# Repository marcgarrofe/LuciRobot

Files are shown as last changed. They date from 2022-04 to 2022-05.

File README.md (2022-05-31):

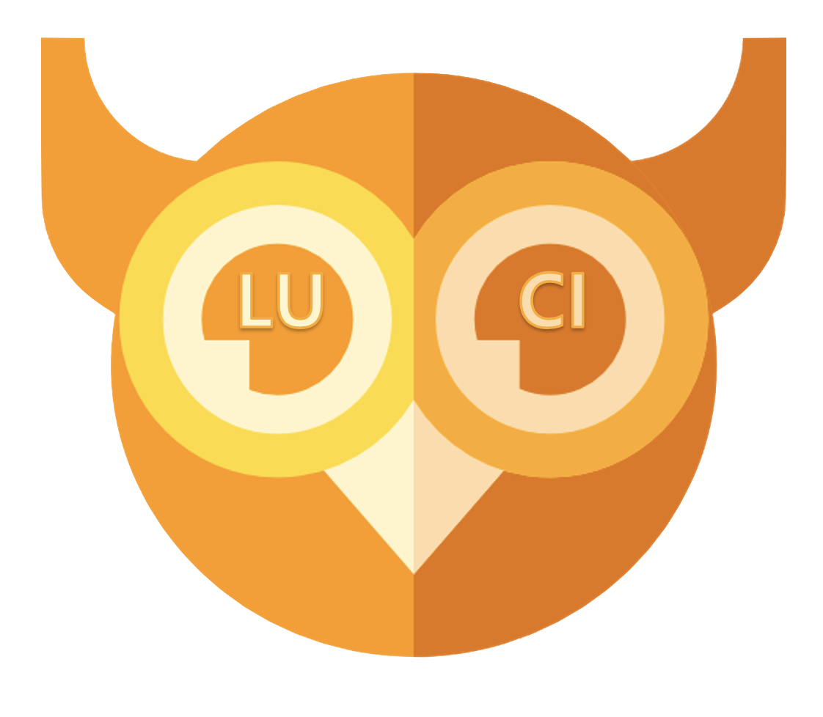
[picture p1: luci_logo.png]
header pic


# Luci
Human seeker robot in hostile environments.

# Table of Contents
   * [What is this?](#what-is-this)
   * [Requirements](#requirements)
   * [How to use](#how-to-use)
   * [Controller panel](#controller-panel)
   * [Driving](#driving-modes)
   * [Speech to text](#speech-to-text)
   * [Image processing](#image-processing)
   * [Person detector](#person-detector)
   * [License](#license)
   * [Contribution](#contribution)
   * [Authors](#authors)

# What is this?

Luci is a human detector robot designed to locate people inside hostile enviroments such as gas, smoke or fire. 

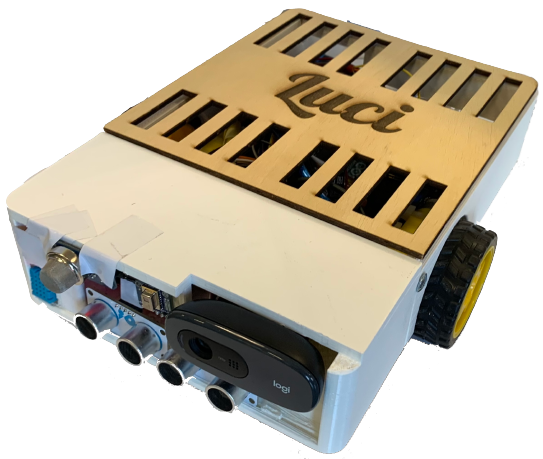
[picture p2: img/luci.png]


Features:

1. Easy to controll and operate.

2. Widely range of sensor and cameras.

3. Small and fast.

# Requirements

For running each sample code:

- [Python 3.10.x](https://www.python.org/)

- [C++]

- [Flask/socket.io](https://socket.io/)

- [PySerial](https://pypi.org/project/pyserial/)

- [OpenCV](https://opencv.org/)

- [VidGear](https://abhitronix.github.io/vidgear/v0.2.5-stable/)

- [Google Cloud Speech](https://cloud.google.com/speech-to-text)

- [PyAudio](https://pypi.org/project/PyAudio/)

- [Adafruit](https://www.adafruit.com/)

- [NumPy](https://numpy.org/)

# How to use

- Step 1:
`cd code`

- Step 2:
`pip install -r requirements.txt` 

- Step 3:
`python main.py`

- Step 4:
Isn't it beautiful?

# Controller panel

Luci has a build-in controller panel web server. Her user-friendly interface allows the operator to see through Luci's eyes and sensors can drive where none can arrive.

Luci's has a wide range of sensors such as: gas sensor, distance, temperature, humidity, microphone and two cameras. You can see all the sensors displaying below:

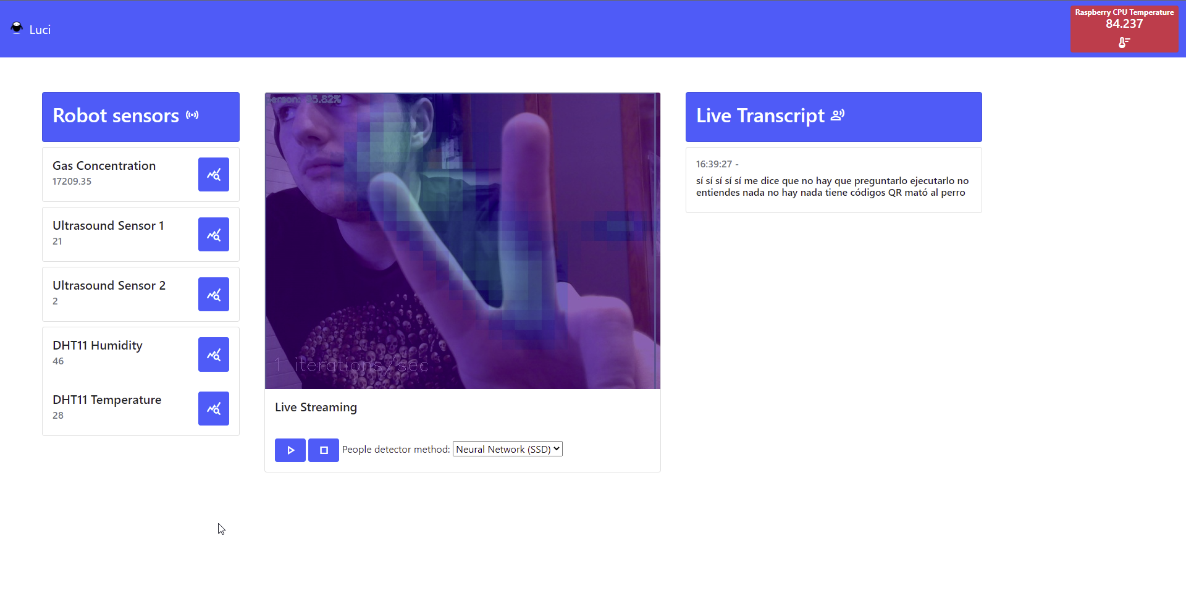
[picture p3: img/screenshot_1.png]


# Driving modes

In order to perform more accurate driving experience, Luci is controlled with a gamepad. This cool feature allows the operator to control each wheal movement and speed separately in order to get a better accuracy movement.

# Speech to text

Luci's microphone can recognize voice and convert it to text. This feature is founded on the controller panel and allows the operator to read the live transcription of the room's voice.

# Image processing

The robot's eyes are formed of a wide-range camera and a thermal camera that combined using image processing provides an RGB realtime image with temperature coloring.

Finally, in order to drive and have a real time image from Luci, she has a build in video stabilization developed with software that uses a wide range of image stabilization such as: KeyPoint matching, Fourier image superposition and Optical Flow. Each age can be called by the operator in order to find the implementation that works best for each situation.

# Person detector

Luci's computer runs a Neuronal Network that detects people and animals in the room. This tool helps the firefighters to identify the number of people inside a building and combined with the thermal camera we can determinate the state of the subject.

# License 

MIT

# Contribution

Any contribution is welcome!! 

# Authors
 * [Marti Caixal](https://github.com/marti1999)
 * [Hernan Capilla](https://github.com/hcapilla)
 * [Marc Garrofe](https://github.com/marcgarrofe)
 * [Ricard Lopez](https://github.com/Ricardlol)
 * [Bruno Moya](https://github.com/elblogbruno)

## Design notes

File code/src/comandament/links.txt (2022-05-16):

https://create.arduino.cc/projecthub/72359/controlling-a-robot-with-a-playstation-controller-15741e
https://pimylifeup.com/raspberry-pi-playstation-controllers/
https://wouterdeschuyter.be/blog/configure-a-ps3-controller-to-automatically-connect-to-a-raspberry-pi

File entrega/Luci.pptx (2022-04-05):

## LUCi

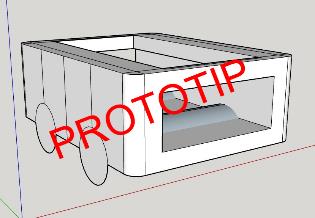
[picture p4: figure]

GROUP_16
Martí Caixal Joaquinet
Hernán Capilla Urbano
Marc Garrofé Urrutia
Ricard Lopez Olivares
Bruno Moya Ruíz

Robot amb l’objectiu de localitzar persones en risc a terrenys hostils per humans

Robòtica, llenguatge I planificació – Enginyeria informàtica - uab

## LUCI

Component | Units | Price/unit | Budget
Raspberry Pi 3 B+ | 1 | 35 | 35
Gravity: Sensor de gases | 1 | 6,5 | 41,5
Sensor de distancia por ultrasondos HC-SR04 | 2 | 1,8 | 45,1
Arduin UNO REV.3, | 1 | 15 | 60,1
Kit motores: DAGU 140RPM | 1 | 5,59 | 65,69
Cable de pila 9V | 1 | 0,79 | 66,48
MLX90640 Thermal Camera Breakout | 1 | 53,55 | 119,55
WEBCAM C160 | 1 | 12,8 | 132,35
Sensor TEMP./HUMEDAD | 1 | 4,02 | 136,37
POWER BANK 5000 | 1 | 7,91 | 144,28
L93B QUAD PUSH | 1 | 2,15 | 146,91
TOTAL: | | | 146,91

## Altres enllaços

Projecte en el qual està inspirat

https://www.eltiempo.com/tecnosfera/novedades-tecnologia/firebot-el-robot-que-ayuda-a-prevenir-incendios-forestales-103122

- https://github.com/gritmind/image-processing-for-fire-detection
- https://makersportal.com/blog/2020/6/8/high-resolution-thermal-camera-with-raspberry-pi-and-mlx90640

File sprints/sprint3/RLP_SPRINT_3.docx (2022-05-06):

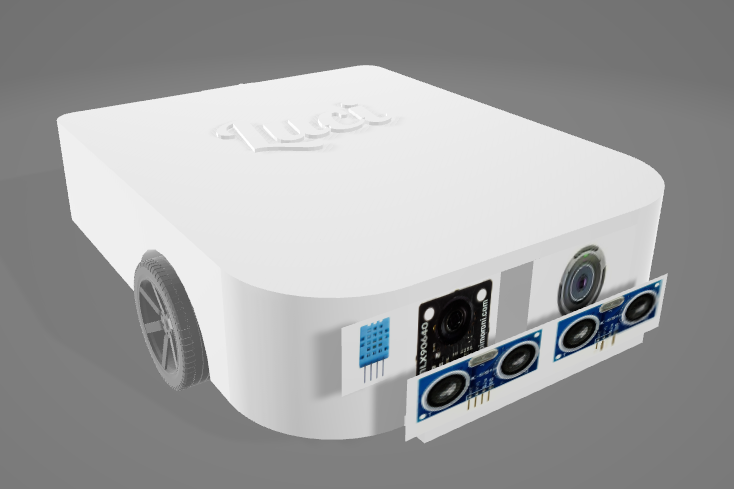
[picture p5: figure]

# Luci

Human seeker robot in hostile environments

PROJECT SPRINT #3.
DATE: 4th May 2022

Martí Caixal i Joniquet
Ricard Lopez Olivares
Hernán Capilla Urbano
Bruno Moya Ruiz
Marc Garrofé Urrutia

Luci

Human seeker robot in hostile environments

# Project description

This robot’s aim is to seek people whose situation is not favorable in hostile environments. It searchs, avoids obstacles, detects humans in environments where people can’t afford to get in (such as gas, smoke, or buildings on fire) and notifies the emergency units.

“Luci keeps you safe, from environments where you won’t be safe.”

# Electronic components

This is the list of the used components:

- Raspberry Pi 3 B+
- Gravity: Gas sensor
- Ultrasound HC-SR04 distance sensor
- Arduino UNO Rev.3
- Motor Kit: DAGU 140rpm
- 9V battery cable
- MLX90640 Thermal Camera Breakout
- Webcam C160
- Temperature/Humidity sensor
- Power Bank 5000
- L93B Quad Push

# Hardware Scheme

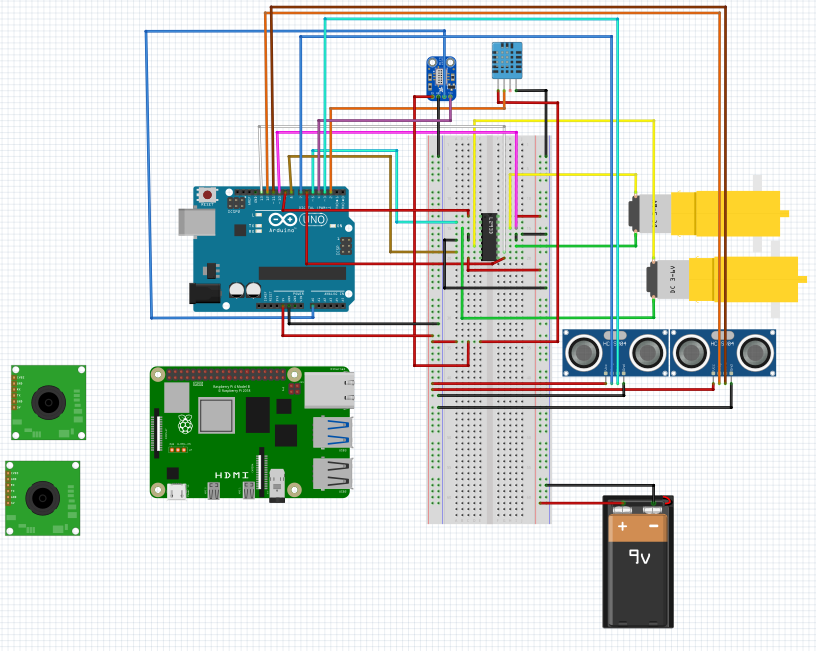
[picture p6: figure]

# Software Architecture

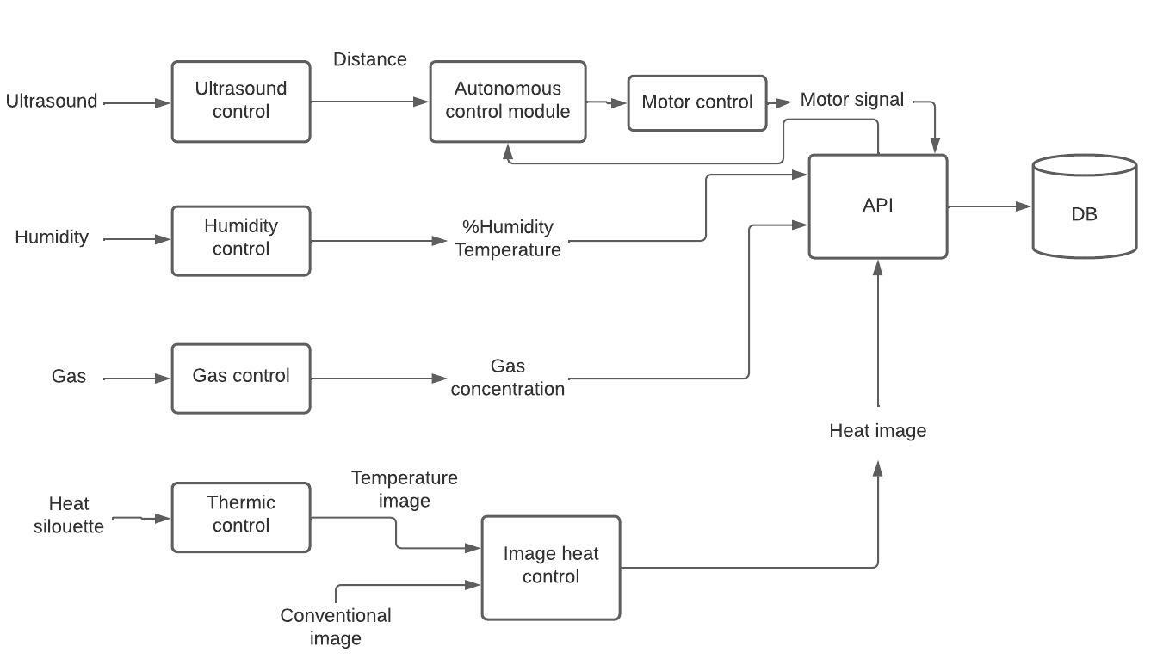
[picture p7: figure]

# Amazing contributions

Mixing Compting Vision + Robotics with the purpose of analyzing normal images and thermic images to get the results.

Adaptive robot to different environments such as gas, fire, smoke, etc.

Not only detects but notifies.

Not only notifies but it also indicates the path that has followed the robot plus the obstacles that have found on its way.

# Extra components and 3D pieces

- Design 3 pieces First we have the base of the robot. This one presents the part for puting the motors and wheels, also with all the essential elements like Arduino or Raspberry.
- Here we can see it empty:

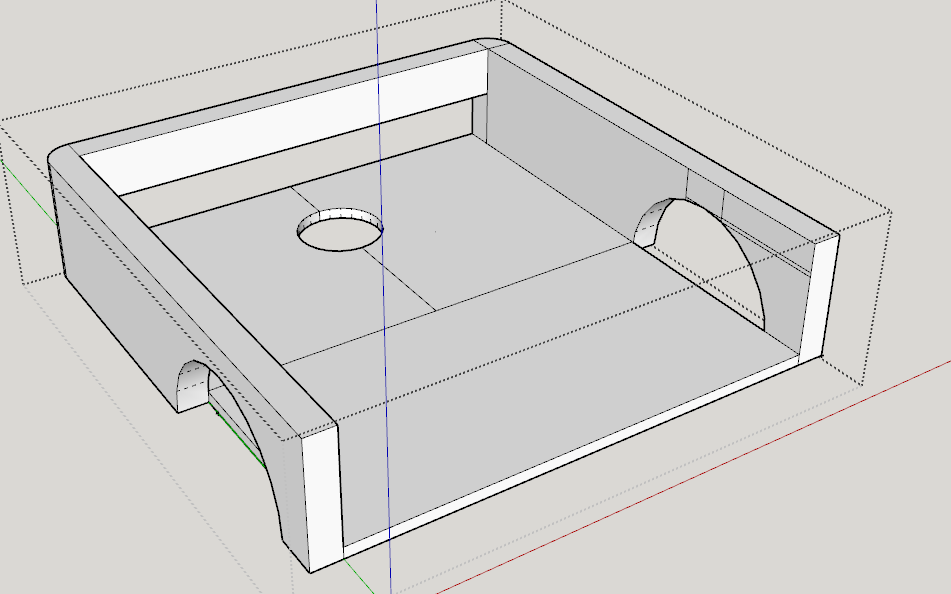
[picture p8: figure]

- The idea of this rectangular format at the end (which is not definitive) is to install all the electronics and in this way to be able to connect the arduino to the computer with the cable, so with the batteries witouth having to take them off. The hole is currently very Big, once we have all the electronics we will try to 'measure' and so the cables do fit in perfectly without having a hole on the back.

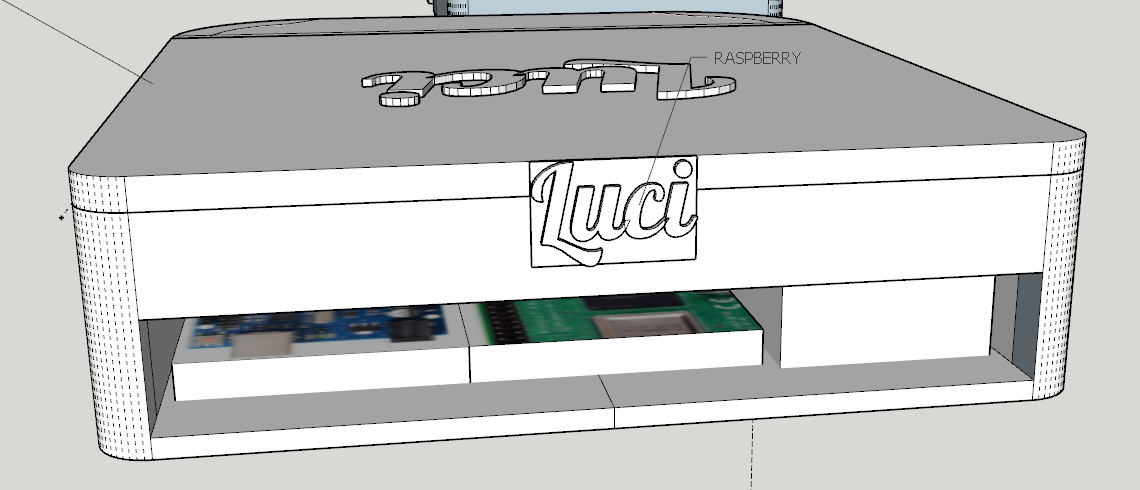
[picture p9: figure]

Next, we have the front part. Here it was necessary to chop the robot in parts due to the the fact that the idea is that everything can be printed on the 3D printer, but apart from that, it presents its benefits.

First of all, it is on where all the sensors and the cameras of the robot will be. Having it separately in a module allows the installation or customization of the module to remain effective without having to modify all the robot chassis. Once all the sensors are plugged in, their cables will go back to where the Arduino and raspberry are.

Attempts have been made to distribute all things so that the robot has a uniform weight around the entire structure, and that it is as small in height as possible so that it can enter more hostile places.

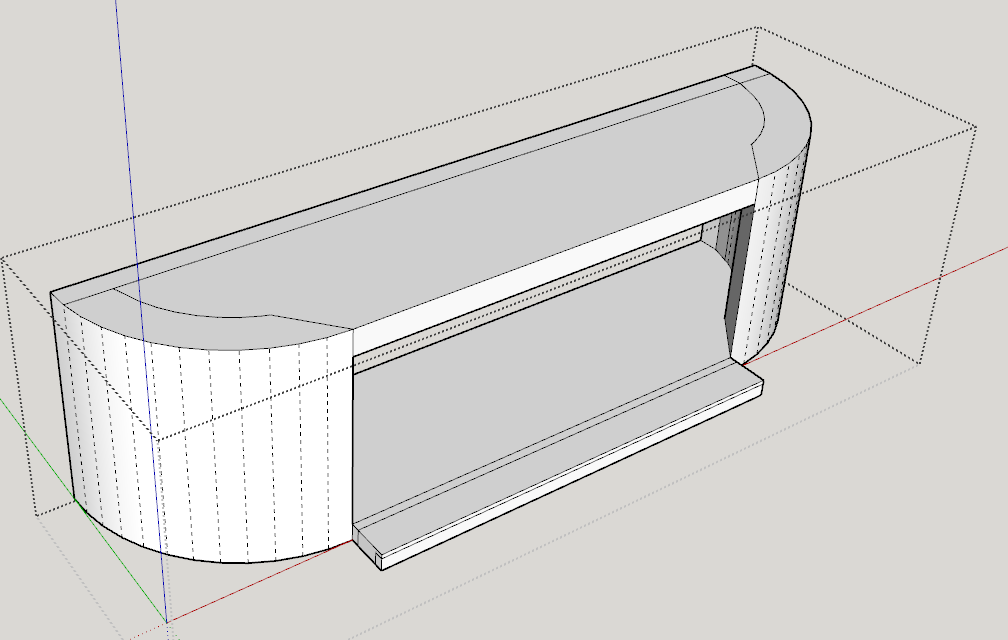
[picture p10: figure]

Finally, we have the cover, which allows us to close the whole system in a homogeneous structure and why not, beautiful, without all the electronics visible and protected at the same time.

The general idea of everything was to make it a versatile and modular robot, to be able to tractor problems individually and also to fit everything in the printing base of a 3D printer.

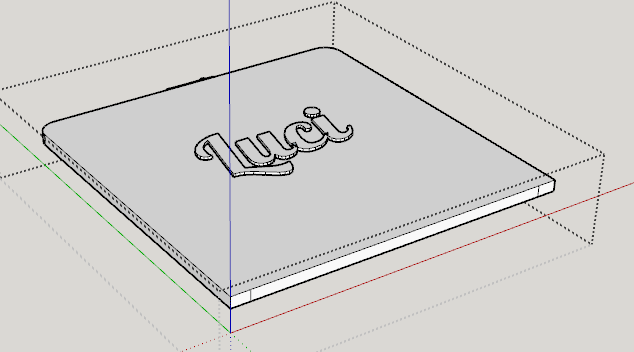
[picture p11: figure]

# Foreseen risks and contingency plan

Risk # | Description | Probability (High/Medium/Low) | Impact (High/Medium/Low) | Contingency plan
1 | Camera not stable | Médium | Low | Stabilize the image sequence although the the FOV would be reduced
2 | Faulty thermal camera | Low | Medium | Refund it and ask for a new camera if possible. Otherwise we would just use the default pi camera for computer vision
3 | Cannot merge both images (normal and thermal camera) | Medium | Medium | Images would be needed to be treated separately. The predictions would likely be worse.
4 | Wheels don’t move smoothly | Medium | Low | The robots would just not move smoothly. If it too much, some smoothing could be created by adding a chicken rubber around the wheels.
5 | Not enough CPU/GPU power | Medium | Medium | Instead of getting the desired 20fps, we would have a lower fps and probably would not be able to use it in real time.
6 | Not enough torque from the motors to move the robot | Low | High | More powerful motors would be required. Another option could be using extra gears to increase torque, but the speed would be decreased.
7 | Don’t know how to connect Arduino and Raspbery pi together | High | Low | We would first try to do it on a PC with a simulator following some tutorials. Once we get to understand it, we would try to do it again now with the physical components.
8 | 3D printed parts are not good or do not fit together with one another or the other electrical components | High | low | If the error is low, we could just file down the edges. Otherwise, some new parts would be to be printed.

# Algo

- OpenCV Optical flow and key points detection in order to stabilizate the camera
- TensorFlow YOLO and SSD neuronal networks for person detection
- MPEG encoding for vídeo streaming

# Updates Sprint 2

- Motors now move in different directions. They go forward, backward, left, right (with the desired speed)
- All sensors working and getting correct input values
- We have python code that reads the sensors values from serial USB and then them them using websockets in real-time to the work in progress javascript-html frontend.
- This allows a communication between Arduino and python in real time, for example for controlling the robot motors from the frontend and whatever idea we want to implement. We can do it either in local or the internet with a free hosting.
- Along with this document, there is a video attached showing the motors move.

# Updates Sprint 3

- On the computer vision field, we are able to identify more than 40 objects using a SSD Deep Learning Net. Also, as a back-up System, we have a Histogram of Gradient Person detector.
- Also, we have developed an image stabilizer using our own module using point feature and homographs translations. As a back-up we have an open-source stabilizer that works better, but it has high latency (about 3 seconds).

As an example, here you can see a testing video (downloaded from Youtube) that we use to see how the stabilizer and the object detector works:

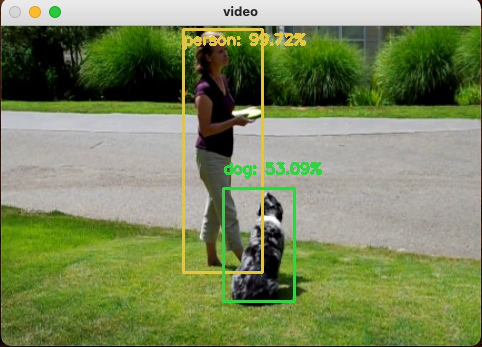
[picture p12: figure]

- Next, we have introduced the communication module between Luci's brain and the operator connected using a web browser. As shown, you can see a basic demonstration of the data coming from the robot's sensors. Thanks to the use of WebSockets (https://socket.io/) we can have this information in real time. This means we can also interact in real time from the dashboard with the raspberry, for example, for sending commands to the raspberry that consequently sends them to the Arduino. This will enable in future updates a control of the robot movement from the website UI.
- We have also added a redesign for it using Bootstrap framework, so it is a nice dashboard to look at, and data is easily available and readable from a human worker perspective:

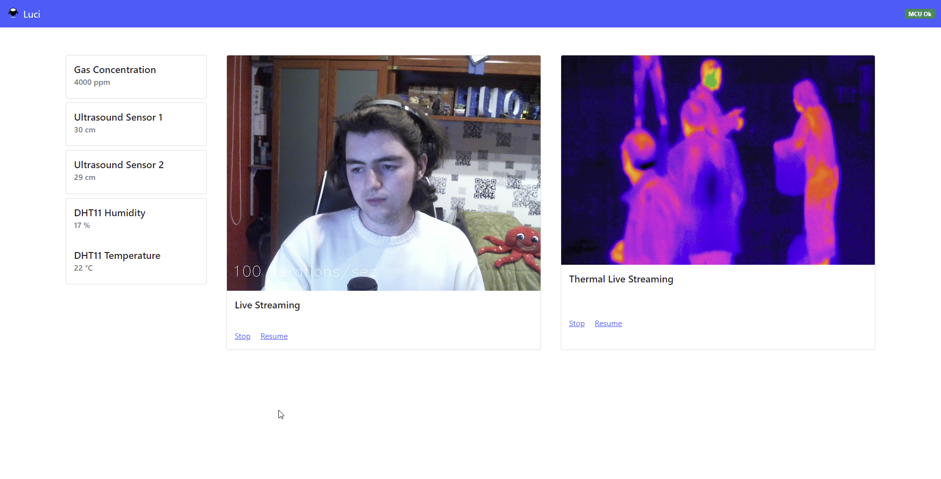
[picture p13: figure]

- Finally, you can see as well that now we also have a live streaming of the RGB Camera (Webcam). The live streaming of the thermal camera by the moment is a placeholder image, as of the time writing this sprint update, has not been given to us or either available on stock (: The catch here it uses threads, that allows us, without any processing of the image yet arrive to greater frames per second. Not only that, but once we connect the computer algorithms seen some lines ago with threads, will allow the raspberry cpu to separate each task on different cpu cores, and do some ‘balancing’
- 3D Wise, we have added some hinge on the cover so we can close and open, but if it adds much unnecessary difficulty to the print, we may remove it and attach the cover with some glue or whatever:

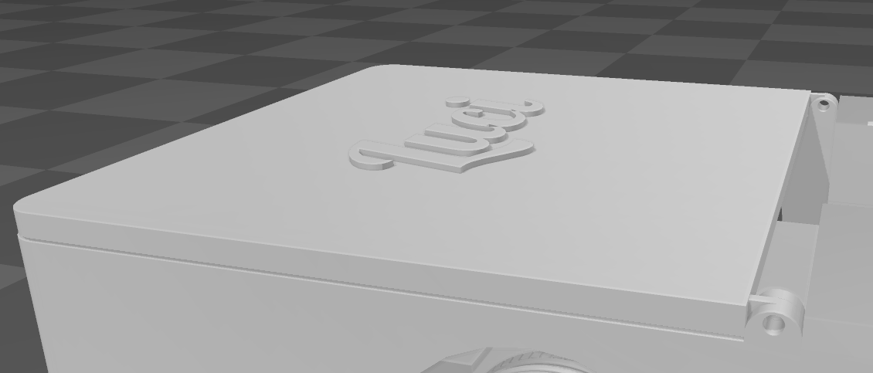
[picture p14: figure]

The sensors part has been redesign for a nicer design but we still are not 100% of it as some sensors may need to be attach with screws, and we prefer something that is easier to print and the sensors to attach:

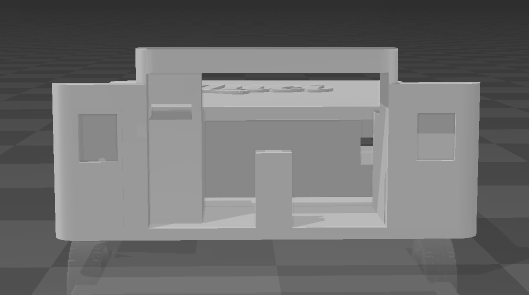
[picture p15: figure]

References

This project has been inspired by the following Internet projects:

URL Link 1: https://www.eltiempo.com/tecnosfera/novedades-tecnologia/firebot-el-robot-que-ayuda-a-prevenir-incendios-forestales-103122

URL Link 2: https://github.com/gritmind/image-processing-for-fire-detection

URL Link 3: https://makersportal.com/blog/2020/6/8/high-resolution-thermal-camera-with-raspberry-pi-and-mlx90640

RLP - Computer Engineering. UAB (Barcelona) 2021-2022

Sprint #1 Date: 14 April 2021

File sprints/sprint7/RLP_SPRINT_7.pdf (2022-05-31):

RLP - Computer Engineering. UAB (Barcelona) 2021-2022

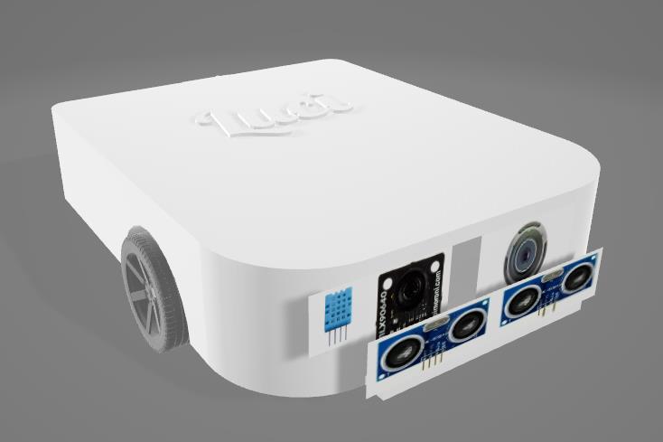
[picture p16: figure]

# Luci

### Human seeker robot in hostile environments

PROJECT SPRINT #7.
DATE: 31th May 2022

Martí Caixal i Joniquet
Ricard Lopez Olivares
Hernán Capilla Urbano
Bruno Moya Ruiz
Marc Garrofé Urrutia

Luci

# Table of Contents

Sprint #6
Date: 25 May 2022
Luci | 1

# Luci

### Human seeker robot in hostile environments

### Project description

This robot’s aim is to seek people whose situation is not favorable in hostile environments. It searchs, avoids obstacles, detects humans in environments where people can’t afford to get in (such as gas, smoke, or buildings on fire) and notifies the emergency units.

“Luci keeps you safe, from environments where you won’t be safe.”

### Electronic components

This is the list of the used components:

◼ Raspberry Pi 3 B+

◼ Gravity: Gas sensor

◼ Ultrasound HC-SR04 distance sensor

◼ Arduino UNO Rev.3

◼ Motor Kit: DAGU 140rpm

◼ 9V battery cable

◼ MLX90640 Thermal Camera Breakout

◼ Webcam C160

◼ Temperature/Humidity sensor

◼ Power Bank 5000

◼ L93B Quad Push

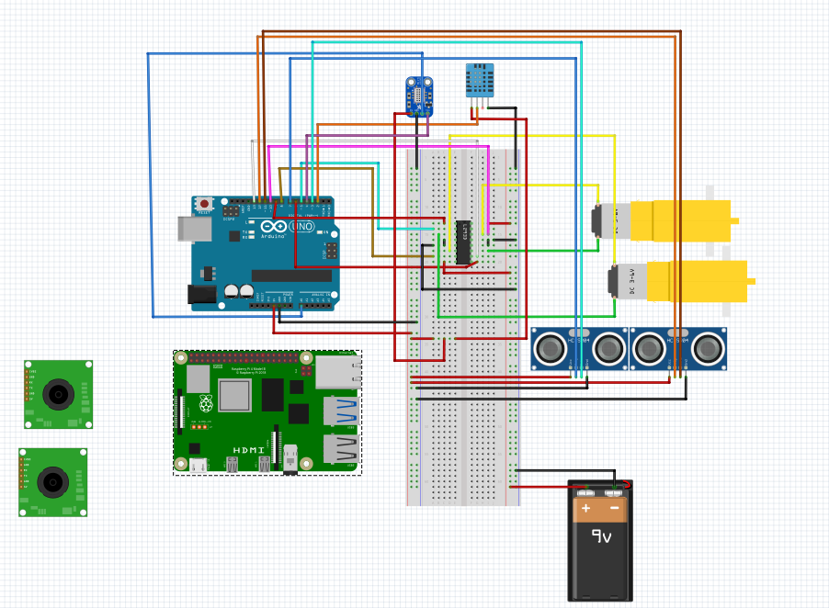
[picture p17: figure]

Luci | 2

### Hardware Scheme

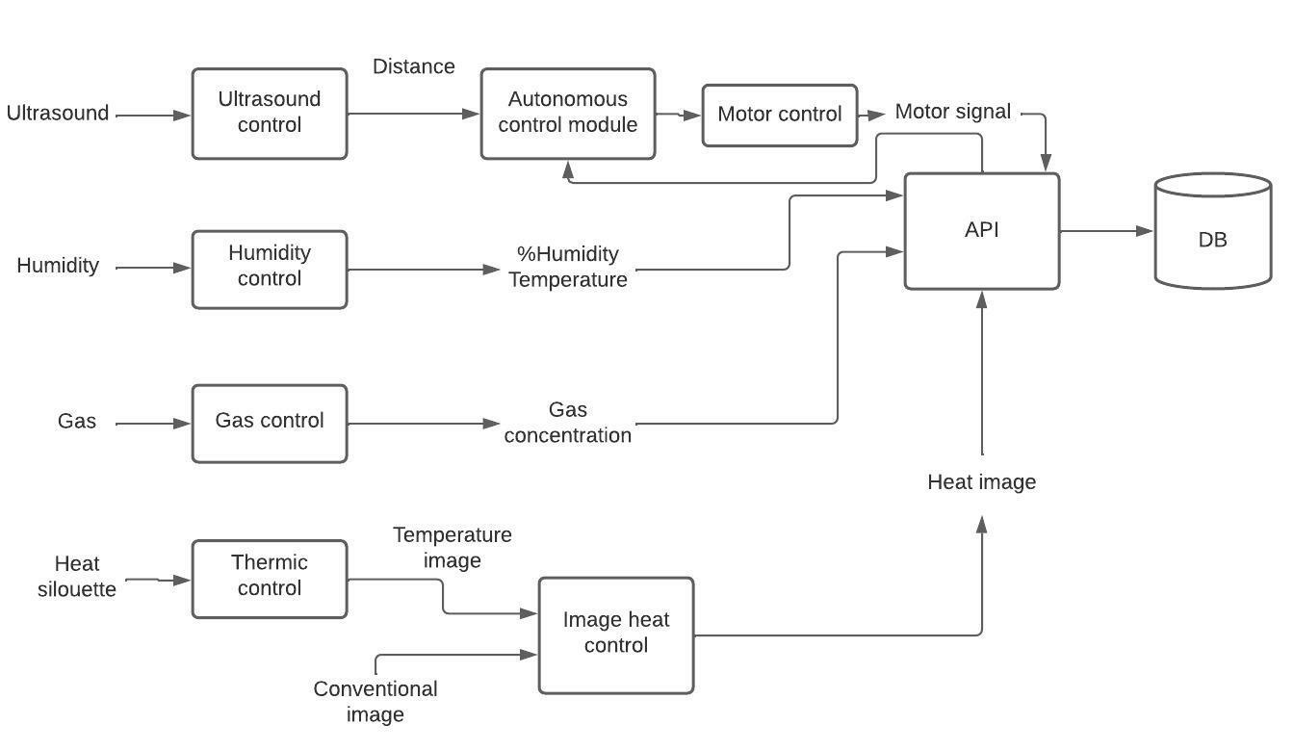
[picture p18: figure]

Luci | 3

### Software Architecture

### Amazing contributions

Mixing Compting Vision + Robotics with the purpose of analyzing normal images and thermic images to get the results.

Adaptive robot to different environments such as gas, fire, smoke, etc.

Not only detects but notifies.

Not only notifies but it also indicates the path that has followed the robot plus the obstacles that have found on its way.

### Extra components and 3D pieces

◼ Design | 3 | pieces
First we have the base of the robot. This one presents the part for puting the motors and wheels, also with all the essential elements like Arduino or Raspberry.

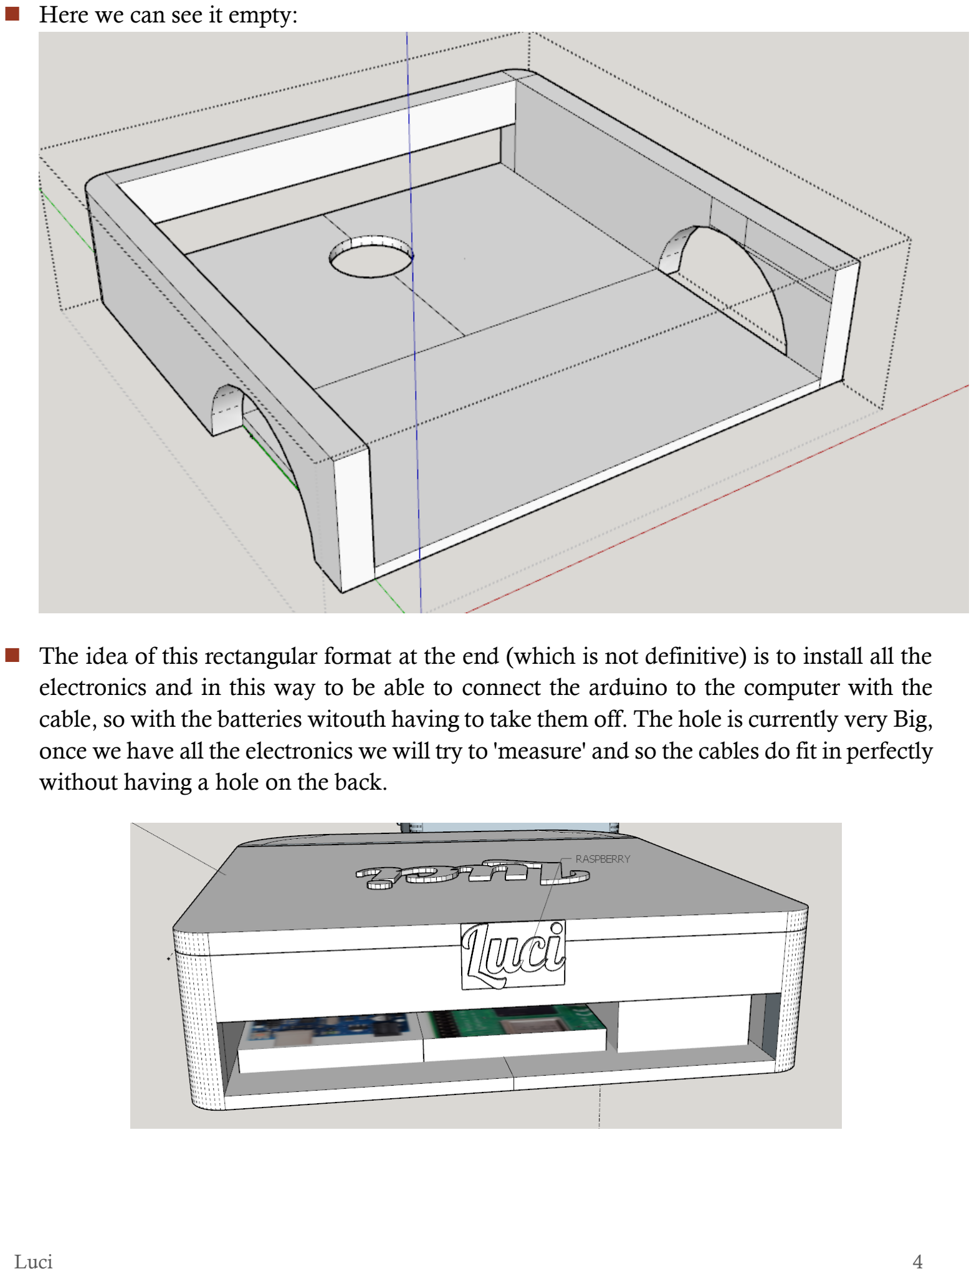
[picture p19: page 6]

Luci | 4

◼ Here we can see it empty:

◼ The idea of this rectangular format at the end (which is not definitive) is to install all the electronics and in this way to be able to connect the arduino to the computer with the cable, so with the batteries witouth having to take them off. The hole is currently very Big, once we have all the electronics we will try to 'measure' and so the cables do fit in perfectly without having a hole on the back.


Luci | 5

Next, we have the front part. Here it was necessary to chop the robot in parts due to the the fact that the idea is that everything can be printed on the 3D printer, but apart from that, it presents its benefits.

First of all, it is on where all the sensors and the cameras of the robot will be. Having it separately in a module allows the installation or customization of the module to remain effective without having to modify all the robot chassis. Once all the sensors are plugged in, their cables will go back to where the Arduino and raspberry are.

Attempts have been made to distribute all things so that the robot has a uniform weight around the entire structure, and that it is as small in height as possible so that it can enter more hostile places.

Finally, we have the cover, which allows us to close the whole system in a homogeneous structure and why not, beautiful, without all the electronics visible and protected at the same time.

The general idea of everything was to make it a versatile and modular robot, to be able to tractor problems individually and also to fit everything in the printing base of a 3D printer.


Luci | 6

### Foreseen risks and contingency plan

Risk # | Description | Probability (High/Medium/Low) | Impact (High/Medium/Low) | Contingency plan
1 | Camera not stable | Médium | Low | Stabilize the image sequence although the the FOV would be reduced
2 | Faulty thermal camera | Low | Medium | Refund it and ask for a new camera if possible. Otherwise we would just use the default pi camera for computer vision
3 | Cannot merge both images (normal and thermal camera) | Medium | Medium | Images would be needed to be treated separately. The predictions would likely be worse.

Luci
7
4 | Wheels don’t move smoothly | Medium | Low | The robots would just not move smoothly. If it too much, some smoothing could be created by adding a chicken rubber around the wheels.
5 | Not enough CPU/GPU power | Medium | Medium | Instead of getting the desired 20fps, we would have a lower fps and probably would not be able to use it in real time.
6 | Not enough torque from the motors to move the robot | Low | High | More powerful motors would be required. Another option could be using extra gears to increase torque, but the speed would be decreased.
7 | Don’t know how to connect Arduino and Raspbery pi together | High | Low | We would first try to do it on a PC with a simulator following some tutorials. Once we get to understand it, we would try to do it again now with the physical components.
8 | 3D printed parts are not good or do not fit | High | low | If the error is low, we could just file down the edges.

Luci | 8

### Algo

- OpenCV Optical flow and key points detection in order to stabilizate the camera
- TensorFlow YOLO and SSD neuronal networks for person detection
- MPEG encoding for vídeo streaming

### Updates Sprint 2

- Motors now move in different directions. They go forward, backward, left, right (with the desired speed)
- All sensors working and getting correct input values
- We have python code that reads the sensors values from serial USB and then them them using websockets in real-time to the work in progress javascript-html frontend.
- This allows a communication between Arduino and python in real time, for example for controlling the robot motors from the frontend and whatever idea we want to implement. We can do it either in local or the internet with a free hosting.
- Along with this document, there is a video attached showing the motors move.

### Updates Sprint 3

- On the computer vision field, we are able to identify more than 40 objects using a SSD Deep Learning Net. Also, as a back-up System, we have a Histogram of Gradient Person detector.
- Also, we have developed an image stabilizer using our own module using point feature and homographs translations. As a back-up we have an open-source stabilizer that works better, but it has high latency (about 3 seconds).

together with
one another
or the other
electrical
components

Otherwise, some
new parts would
be to be printed.

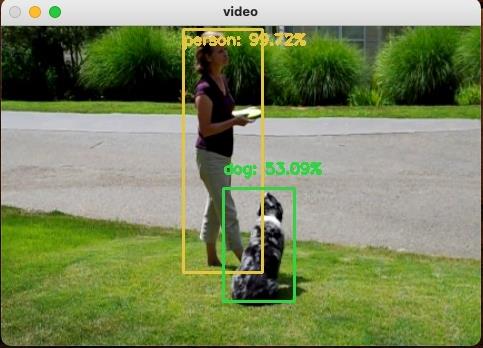
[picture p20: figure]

Luci | 9

As an example, here you can see a testing video (downloaded from Youtube) that we use to see how the stabilizer and the object detector works:

- Next, we have introduced the communication module between Luci's brain and the operator connected using a web browser. As shown, you can see a basic demonstration of the data coming from the robot's sensors. Thanks to the use of WebSockets (https://socket.io/) we can have this information in real time. This means we can also interact in real time from the dashboard with the raspberry, for example, for sending commands to the raspberry that consequently sends them to the Arduino. This will enable in future updates a control of the robot movement from the website UI.
- We have also added a redesign for it using Bootstrap framework, so it is a nice dashboard to look at, and data is easily available and readable from a human worker perspective:

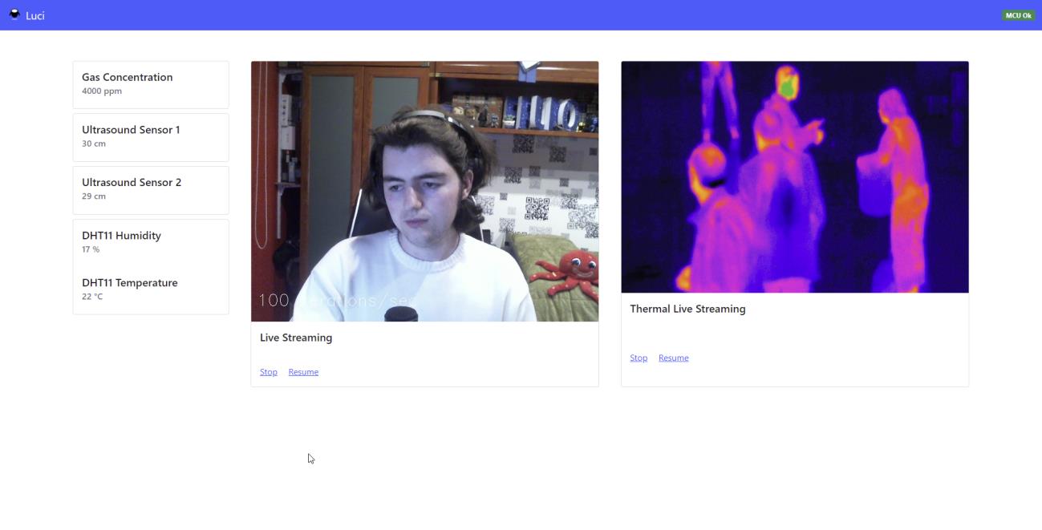
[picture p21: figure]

Luci | 10
- Finally, you can see as well that now we also have a live streaming of the RGB Camera (Webcam). The live streaming of the thermal camera by the moment is a placeholder image, as of the time writing this sprint update, has not been given to us or either available on stock (: The catch here it uses threads, that allows us, without any processing of the image yet arrive to greater frames per second. Not only that, but once we connect the computer algorithms seen some lines ago with threads, will allow the raspberry cpu to separate each task on different cpu cores, and do some ‘balancing’
- 3D Wise, we have added some hinge on the cover so we can close and open, but if it adds much unnecessary difficulty to the print, we may remove it and attach the cover with some glue or whatever:

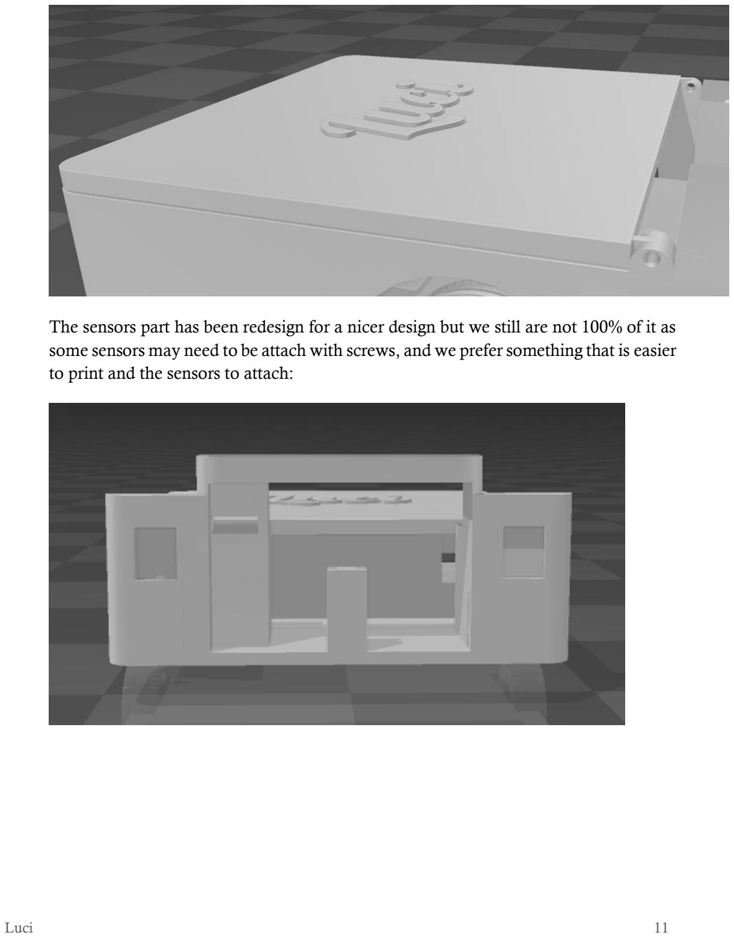
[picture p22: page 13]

Luci | 11

The sensors part has been redesign for a nicer design but we still are not 100% of it as some sensors may need to be attach with screws, and we prefer something that is easier to print and the sensors to attach:

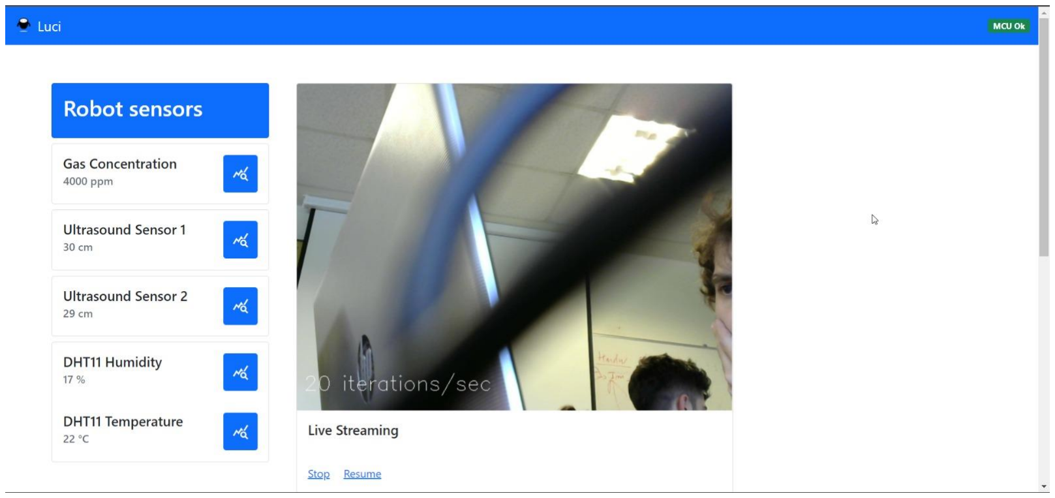
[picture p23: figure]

Luci | 12

### Updates Sprint 4

During this week we have made tests with both cameras (pi noir and usb), how to connect them to the raspberry, how to read data, how to send both videos to the websocket we created and show it on the website.

TODO’s :

1. Ricard - Merge camera image
2. Martí - Use the console gamepad to control the Robot
3. Bruno - 3D print and physically build the robot
4. Hernan - Apply to the raspberry the AI algorithm we created on Python to detect people.
5. Marc - Selft driving
6. Bruno – show voice recognition text on the web

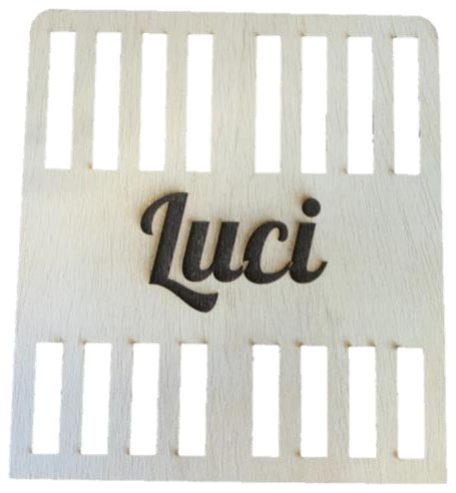
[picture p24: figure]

Luci | 13

### Updates Sprint 6

- During the final weeks, we've printed our robots using 3D printers and wood laser cutting machines in order to manufacture the base and the cover of Luci.
- As you can see, we have modified the main cover of Luci to increase temperature regulation and improve cable managing.
- On the software side, we have a fully working driving manual controller that works flawlessly using a gamepad controller.
- Despite of the transportation delays, we've received our thermal camera and our team has been able to get real time image from the device.
- In recent tests, we have found computer-performance issues while executing the person-detector neuronal network on the Raspberry Pi 4. In consequence, we tried our best to externalize the heaviest process to a laptop.
- During the externalization process, we have added more applications to plot the sensors data on the robot's live webpage.

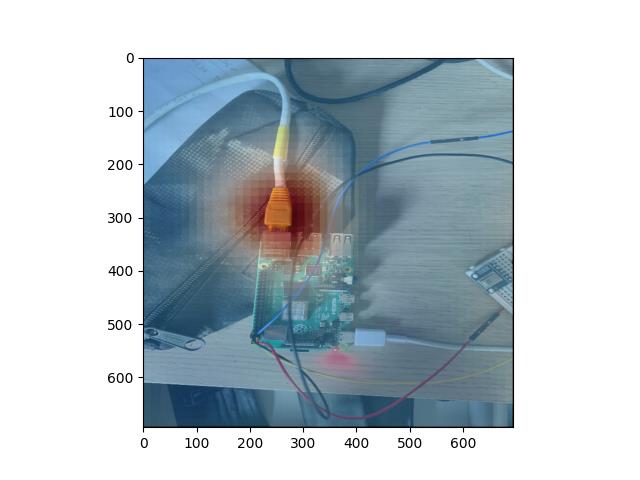
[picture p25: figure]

Luci | 14
- Fusion the image RGB(Logitech camera) and camera termic, the next picture is a prototype with simulated images.
- Finish the hardware deployment and verify that all software component work correctly, for example: graphics sensors, manual driving, fusion images with termal camera and camera RGB, etc.
- Finish the sliders and presentation video.

Luci | 15

# References

This project has been inspired by the following Internet projects:

URL Link 1: https://www.eltiempo.com/tecnosfera/novedades-tecnologia/firebot-el-robot-que-ayuda-a-prevenir-incendios-forestales-103122 (https://www.eltiempo.com/tecnosfera/novedades-tecnologia/firebot-el-robot-que-ayuda-a-prevenir-incendios-forestales-103122)

URL Link 2: https://github.com/gritmind/image-processing-for-fire-detection

URL Link 3: https://makersportal.com/blog/2020/6/8/high-resolution-thermal-camera-with-raspberry-pi-and-mlx90640 (https://makersportal.com/blog/2020/6/8/high-resolution-thermal-camera-with-raspberry-pi-and-mlx90640)

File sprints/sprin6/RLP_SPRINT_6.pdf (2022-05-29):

RLP - Computer Engineering. UAB (Barcelona) 2021-2022


# Luci

### Human seeker robot in hostile environments

PROJECT SPRINT #6.
DATE: 25th May 2022

Martí Caixal i Joniquet
Ricard Lopez Olivares
Hernán Capilla Urbano
Bruno Moya Ruiz
Marc Garrofé Urrutia

Luci

# Table of Contents

Sprint #6
Date: 25 May 2022
Luci | 1

# Luci

### Human seeker robot in hostile environments

### Project description

This robot’s aim is to seek people whose situation is not favorable in hostile environments. It searchs, avoids obstacles, detects humans in environments where people can’t afford to get in (such as gas, smoke, or buildings on fire) and notifies the emergency units.

“Luci keeps you safe, from environments where you won’t be safe.”

### Electronic components

This is the list of the used components:

◼ Raspberry Pi 3 B+

◼ Gravity: Gas sensor

◼ Ultrasound HC-SR04 distance sensor

◼ Arduino UNO Rev.3

◼ Motor Kit: DAGU 140rpm

◼ 9V battery cable

◼ MLX90640 Thermal Camera Breakout

◼ Webcam C160

◼ Temperature/Humidity sensor

◼ Power Bank 5000

◼ L93B Quad Push

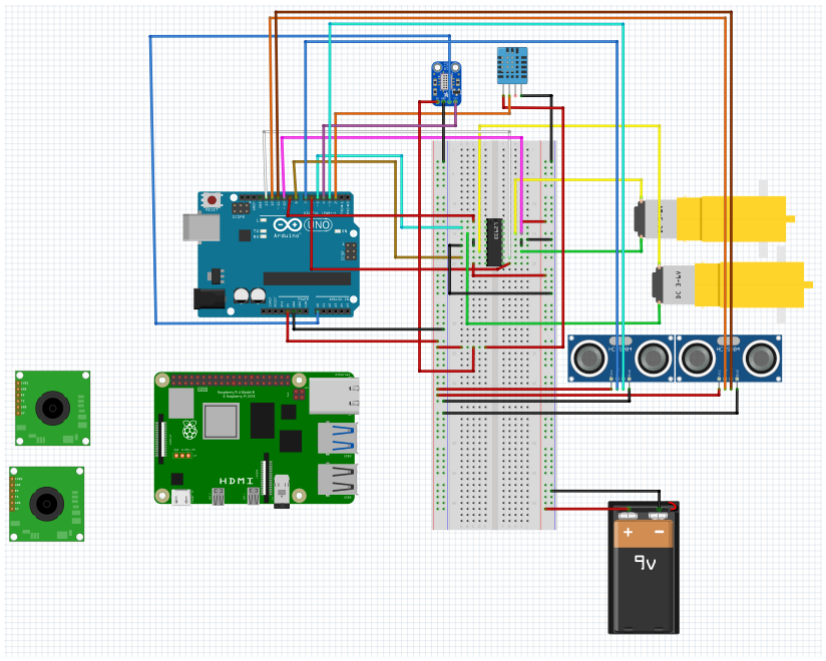
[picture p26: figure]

Luci | 2

### Hardware Scheme


Luci | 3

### Software Architecture

### Amazing contributions

Mixing Compting Vision + Robotics with the purpose of analyzing normal images and thermic images to get the results.

Adaptive robot to different environments such as gas, fire, smoke, etc.

Not only detects but notifies.

Not only notifies but it also indicates the path that has followed the robot plus the obstacles that have found on its way.

### Extra components and 3D pieces

◼ Design | 3 | pieces
First we have the base of the robot. This one presents the part for puting the motors and wheels, also with all the essential elements like Arduino or Raspberry.

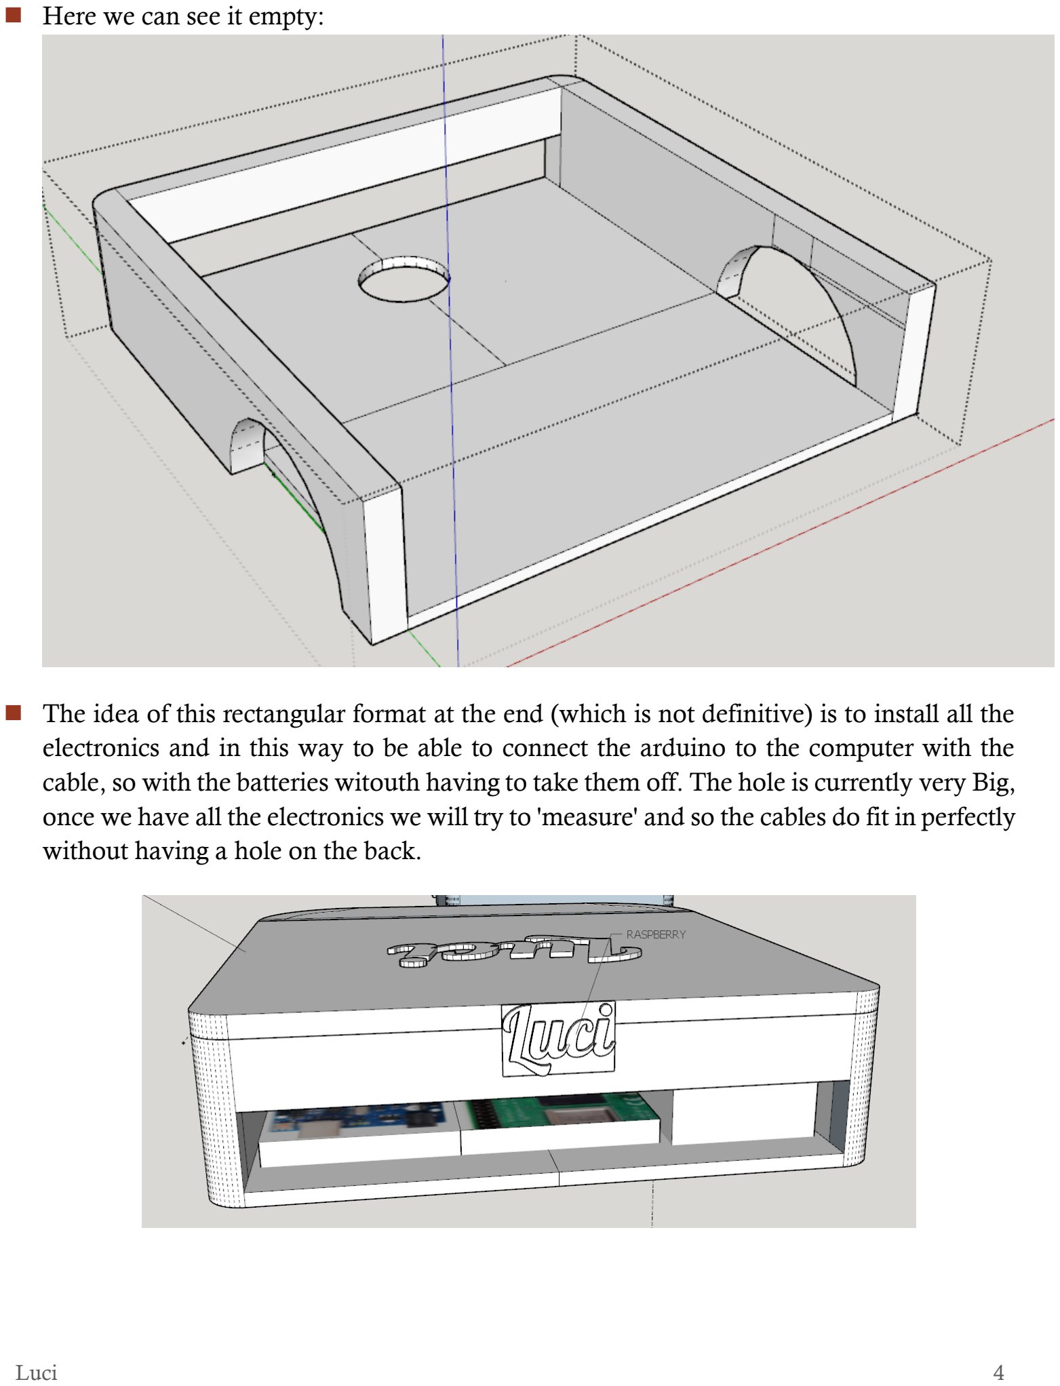
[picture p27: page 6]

Luci | 4

◼ Here we can see it empty:

◼ The idea of this rectangular format at the end (which is not definitive) is to install all the electronics and in this way to be able to connect the arduino to the computer with the cable, so with the batteries witouth having to take them off. The hole is currently very Big, once we have all the electronics we will try to 'measure' and so the cables do fit in perfectly without having a hole on the back.


Luci | 5

Next, we have the front part. Here it was necessary to chop the robot in parts due to the the fact that the idea is that everything can be printed on the 3D printer, but apart from that, it presents its benefits.

First of all, it is on where all the sensors and the cameras of the robot will be. Having it separately in a module allows the installation or customization of the module to remain effective without having to modify all the robot chassis. Once all the sensors are plugged in, their cables will go back to where the Arduino and raspberry are.

Attempts have been made to distribute all things so that the robot has a uniform weight around the entire structure, and that it is as small in height as possible so that it can enter more hostile places.

Finally, we have the cover, which allows us to close the whole system in a homogeneous structure and why not, beautiful, without all the electronics visible and protected at the same time.

The general idea of everything was to make it a versatile and modular robot, to be able to tractor problems individually and also to fit everything in the printing base of a 3D printer.


Luci | 6

### Foreseen risks and contingency plan

Risk # | Description | Probability (High/Medium/Low) | Impact (High/Medium/Low) | Contingency plan
1 | Camera not stable | Médium | Low | Stabilize the image sequence although the the FOV would be reduced
2 | Faulty thermal camera | Low | Medium | Refund it and ask for a new camera if possible. Otherwise we would just use the default pi camera for computer vision
3 | Cannot merge both images (normal and thermal camera) | Medium | Medium | Images would be needed to be treated separately. The predictions would likely be worse.

Luci
7
4 | Wheels don’t move smoothly | Medium | Low | The robots would just not move smoothly. If it too much, some smoothing could be created by adding a chicken rubber around the wheels.
5 | Not enough CPU/GPU power | Medium | Medium | Instead of getting the desired 20fps, we would have a lower fps and probably would not be able to use it in real time.
6 | Not enough torque from the motors to move the robot | Low | High | More powerful motors would be required. Another option could be using extra gears to increase torque, but the speed would be decreased.
7 | Don’t know how to connect Arduino and Raspbery pi together | High | Low | We would first try to do it on a PC with a simulator following some tutorials. Once we get to understand it, we would try to do it again now with the physical components.
8 | 3D printed parts are not good or do not fit | High | low | If the error is low, we could just file down the edges.

Luci | 8

### Algo

- OpenCV Optical flow and key points detection in order to stabilizate the camera
- TensorFlow YOLO and SSD neuronal networks for person detection
- MPEG encoding for vídeo streaming

### Updates Sprint 2

- Motors now move in different directions. They go forward, backward, left, right (with the desired speed)
- All sensors working and getting correct input values
- We have python code that reads the sensors values from serial USB and then them them using websockets in real-time to the work in progress javascript-html frontend.
- This allows a communication between Arduino and python in real time, for example for controlling the robot motors from the frontend and whatever idea we want to implement. We can do it either in local or the internet with a free hosting.
- Along with this document, there is a video attached showing the motors move.

### Updates Sprint 3

- On the computer vision field, we are able to identify more than 40 objects using a SSD Deep Learning Net. Also, as a back-up System, we have a Histogram of Gradient Person detector.
- Also, we have developed an image stabilizer using our own module using point feature and homographs translations. As a back-up we have an open-source stabilizer that works better, but it has high latency (about 3 seconds).

together with
one another
or the other
electrical
components

Otherwise, some
new parts would
be to be printed.


Luci | 9

As an example, here you can see a testing video (downloaded from Youtube) that we use to see how the stabilizer and the object detector works:

- Next, we have introduced the communication module between Luci's brain and the operator connected using a web browser. As shown, you can see a basic demonstration of the data coming from the robot's sensors. Thanks to the use of WebSockets (https://socket.io/) we can have this information in real time. This means we can also interact in real time from the dashboard with the raspberry, for example, for sending commands to the raspberry that consequently sends them to the Arduino. This will enable in future updates a control of the robot movement from the website UI.
- We have also added a redesign for it using Bootstrap framework, so it is a nice dashboard to look at, and data is easily available and readable from a human worker perspective:


Luci | 10
- Finally, you can see as well that now we also have a live streaming of the RGB Camera (Webcam). The live streaming of the thermal camera by the moment is a placeholder image, as of the time writing this sprint update, has not been given to us or either available on stock (: The catch here it uses threads, that allows us, without any processing of the image yet arrive to greater frames per second. Not only that, but once we connect the computer algorithms seen some lines ago with threads, will allow the raspberry cpu to separate each task on different cpu cores, and do some ‘balancing’
- 3D Wise, we have added some hinge on the cover so we can close and open, but if it adds much unnecessary difficulty to the print, we may remove it and attach the cover with some glue or whatever:


Luci | 11

The sensors part has been redesign for a nicer design but we still are not 100% of it as some sensors may need to be attach with screws, and we prefer something that is easier to print and the sensors to attach:


Luci | 12

### Updates Sprint 4

During this week we have made tests with both cameras (pi noir and usb), how to connect them to the raspberry, how to read data, how to send both videos to the websocket we created and show it on the website.

TODO’s :

1. Ricard - Merge camera image
2. Martí - Use the console gamepad to control the Robot
3. Bruno - 3D print and physically build the robot
4. Hernan - Apply to the raspberry the AI algorithm we created on Python to detect people.
5. Marc - Selft driving
6. Bruno – show voice recognition text on the web


Luci | 13

### Updates Sprint 6

- During the final weeks, we've printed our robots using 3D printers and wood laser cutting machines in order to manufacture the base and the cover of Luci.
- As you can see, we have modified the main cover of Luci to increase temperature regulation and improve cable managing.
- On the software side, we have a fully working driving manual controller that works flawlessly using a gamepad controller.
- Despite of the transportation delays, we've received our thermal camera and our team has been able to get real time image from the device.
- In recent tests, we have found computer-performance issues while executing the person-detector neuronal network on the Raspberry Pi 4. In consequence, we tried our best to externalize the heaviest process to a laptop.
- During the externalization process, we have added more applications to plot the sensors data on the robot's live webpage.


Luci | 14
- Fusion the image RGB(Logitech camera) and camera termic, the next picture is a prototype with simulated images.

TODO's:

- We are planning to finalize the hardware deployment this week and then verify that all software components work correctly.
- Also, when all the software and hardware parts will finish all tests, will do the final presentation video.

Luci | 15

# References

This project has been inspired by the following Internet projects:

URL Link 1: https://www.eltiempo.com/tecnosfera/novedades-tecnologia/firebot-el-robot-que-ayuda-a-prevenir-incendios-forestales-103122 (https://www.eltiempo.com/tecnosfera/novedades-tecnologia/firebot-el-robot-que-ayuda-a-prevenir-incendios-forestales-103122)

URL Link 2: https://github.com/gritmind/image-processing-for-fire-detection

URL Link 3: https://makersportal.com/blog/2020/6/8/high-resolution-thermal-camera-with-raspberry-pi-and-mlx90640 (https://makersportal.com/blog/2020/6/8/high-resolution-thermal-camera-with-raspberry-pi-and-mlx90640)

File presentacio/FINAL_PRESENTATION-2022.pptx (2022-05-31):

## LUCI


Robot amb l’objectiu de localitzar persones en risc a terrenys hostils per humans

Robòtica, llenguatge I planificació – Enginyeria informàtica - uab

pd: no és un sandwich (:

Martí Caixal i Joaquinet
Hernán Capilla Urbano
Marc Garrofé Urrutia
Ricard Lopez Olivares
Bruno Moya Ruíz

## 1. Arquitectura hardware i software


## 2. Algorísmica


Conducció: Gamepad controlat per Python i envia instruccions a l’Arduino per Serial
IA: SSD ResNet per detectar persones
Fusió de càmeres: ajuntar la imatge de la càmera tèrmica (8x8 pixels) i la normal, fent interpolació bicúbica de la tèrmica per fer-la més gran de el que realment és.
Google Cloud: Speech to text per aconseguir transcripció en temps real del que recull el micròfon del robot.
Servidor amb Flask i websockets: Permet veure les imatges de les càmeres en streaming, dades i gràfiques en temps real dels sensors i la transcripció en temps real.

## FOTOS, VIDEO i Git

https://youtu.be/AkMvN83UQ1Q

https://github.com/marcgarrofe/RLP-PLAB

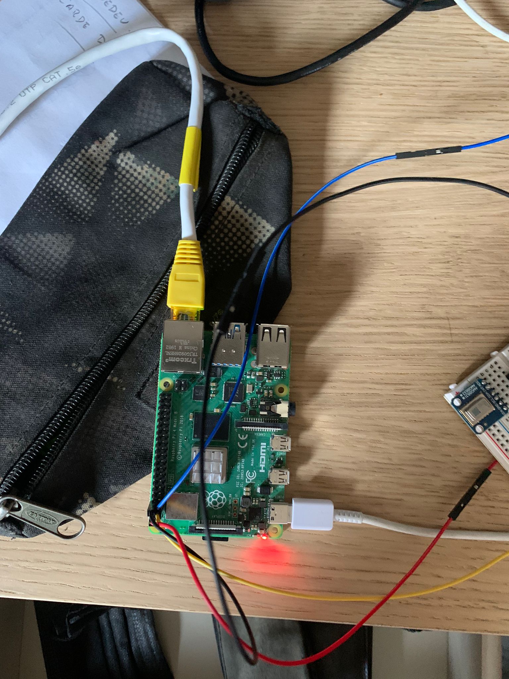
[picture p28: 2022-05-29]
code/src/MergeImage/img/normal.jpeg

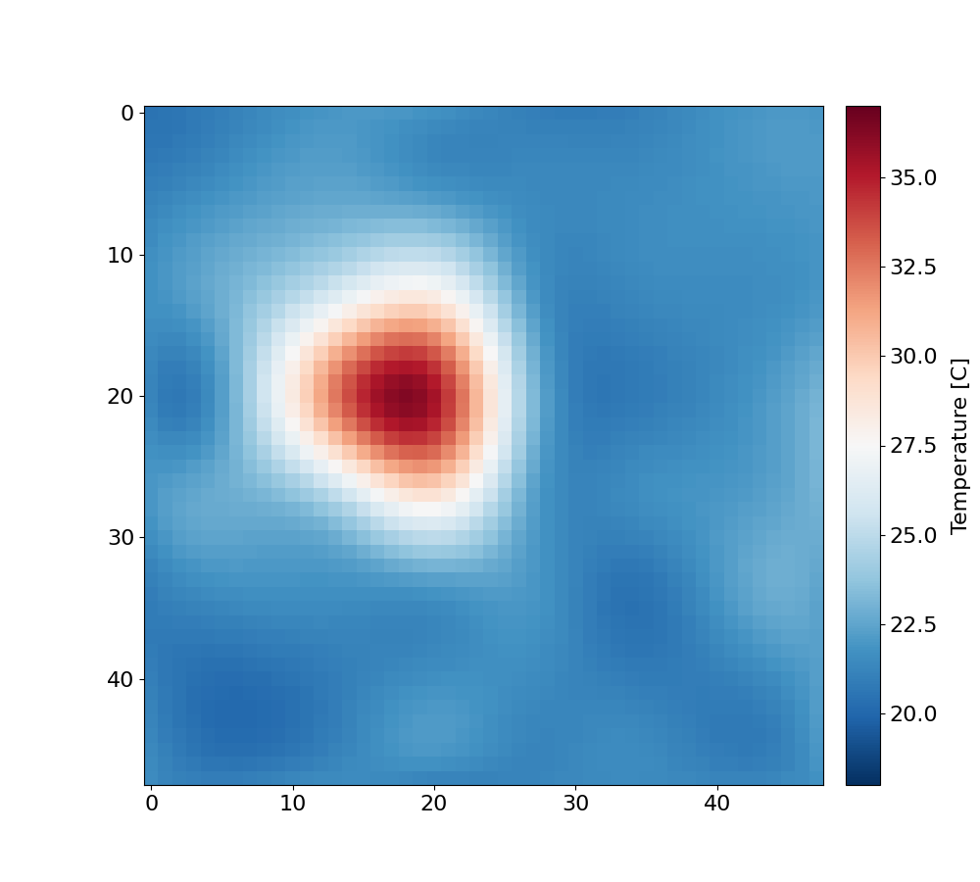
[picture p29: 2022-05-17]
code/src/MergeImage/img/save.png

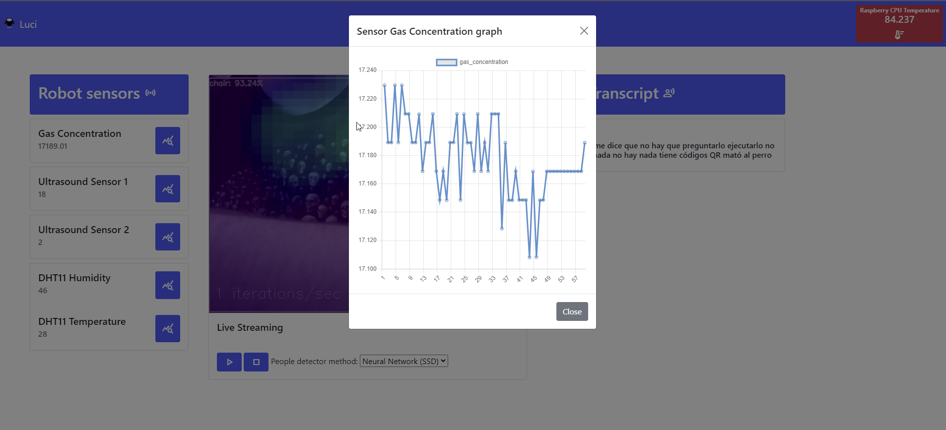
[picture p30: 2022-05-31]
img/screenshot_2.png

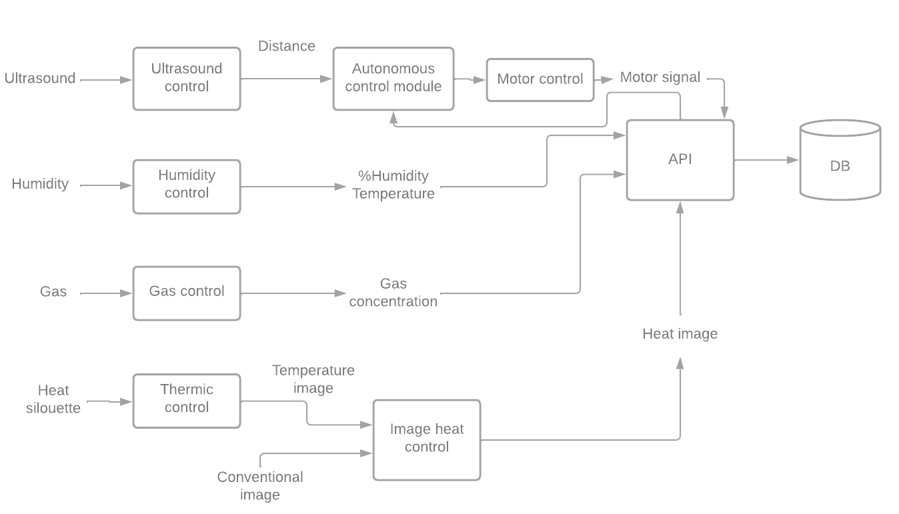
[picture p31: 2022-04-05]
img/SW-Diagram.png

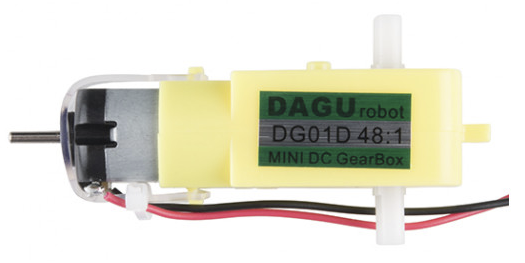
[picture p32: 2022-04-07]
3d/motor.png

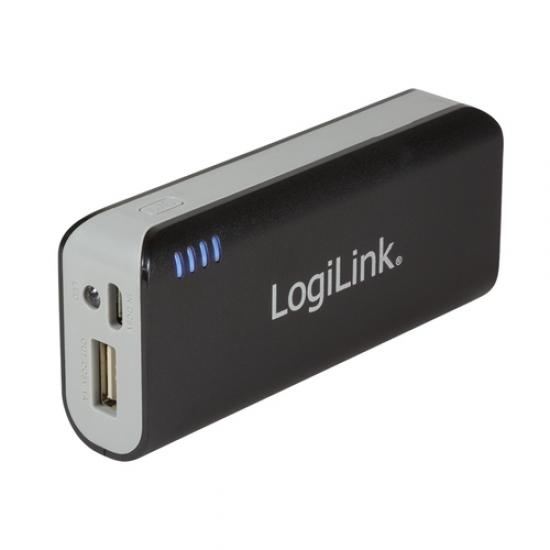
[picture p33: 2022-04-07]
3d/3376cf8561f3804127955ba0f30886275f68845f_original.jpeg

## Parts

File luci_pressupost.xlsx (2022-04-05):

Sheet: tienda.bricogeek.com
TOTAL DEL PROJECTE (automàtic) |  |  | 146.91
(Aferir-hi tots els components necessaris)
# | Component | Referncia | Preu € | Unitats | Total | URL
1 | Raspberry Pi 3 B+ | RSP-0046 | 42.95 | 1 | 35 | https://tienda.bricogeek.com/placas-raspberry-pi/1089-raspberry-pi-3-b-plus.html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
2 | Gravity: Sensor de Gases para Arduino (MQ2) | SEN-0101 | 6.5 | 1 | 6.5 | https://tienda.bricogeek.com/sensores-gas/1223-gravity-sensor-de-gases-para-arduino-mq2.html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
3 | Sensor de distancia por ultrasonidos HC-SR04 | SEN-0054 | 1.8 | 2 | 3.6 | https://tienda.bricogeek.com/sensores-distancia/741-sensor-de-distancia-por-ultrasonidos-hc-sr04.html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
4 | Arduino UNO Rev.3 | ARD-0032 | 19.95 | 1 | 15 | https://tienda.bricogeek.com/arduino/305-arduino-uno.html?search_query=arduino+uno&results=88
5 | Kit motores Dagu 140RPM (2 unidades) | DCM-0048 | 5.59 | 1 | 5.59 | https://tienda.bricogeek.com/motores-dc/1607-kit-motores-dagu-140rpm-2-unidades.html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
6 | Cable para pila de 9V | PRO-0102 | 0.79 | 1 | 0.79 | https://tienda.bricogeek.com/cables/650-cable-para-pila-de-9v.html?search_query=conector+pila+9+&results=45
7 | MLX90640 Thermal Camera Breakout |  | 53.55 | 1 | 53.55 | https://shop.pimoroni.com/products/mlx90640-thermal-camera-breakout?variant=12536948654163
 |  |  |  | Total | 120.03
 |  | 45 para raspberry
 |  | 15 para arduino |  | arduino se puede obvia
 |  |  |  | cosas que falta si o si
 |  |  |  | bateria de 5 volts per a la raspberry y alimentacion separada para los motores
 |  |  |  | motor si queremos girar

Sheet: www.diotronic.com
TOTAL DEL PROJECTE (automàtic) |  |  | 146.91
(Aferir-hi tots els components necessaris)
# | Component | Referncia | Preu € | Unitats | Total | URL
1 | WEBCAM C160 | 960-000650 | 12.8 | 1 | 12.8 | https://diotronic.com/webcams-/4079-mini-webcam-300k-pix-raspberry
2 | SENSOR TEMP./HUMEDAD DHT11 | VMA311 | 4.02 | 1 | 4.02 | https://diotronic.com/accesorios-y-sensores/15255-sensor-temp-humedad-dht11
3 | Power bank 5000 mAh, 1x USB-A | PA0084B | 7.91 | 1 | 7.91 | https://diotronic.com/powerbanks/17660-power-bank-5000-mah-1x-usb-a
4 | L293B QUAD PUSH PULL DRIVER | L293 | 2.15 | 1 | 2.15 | https://diotronic.com/drivers-acondicionadores-receptores-linea/8629-l293b-quad-push-pull-driver
5 |  |  |  |  | 0
6 |  |  |  |  | 0
7 |  |  |  |  | 0
8 |  |  |  |  | 0
 |  |  |  | Total | 26.88

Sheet: es.farnell.com
TOTAL DEL PROJECTE (automàtic) |  |  | 146.91
(Aferir-hi tots els components necessaris)
# | Component | Referncia | Preu € | Unitats | Total | URL
1
2
3
4
5
6
7
8
 |  |  |  | Total

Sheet: www.electan.com
TOTAL DEL PROJECTE (automàtic) |  |  | 146.91
(Aferir-hi tots els components necessaris)
# | Component | Referncia | Preu € | Unitats | Total | URL
1
2
3
4
5
6
7
8
 |  |  |  | Total | 0

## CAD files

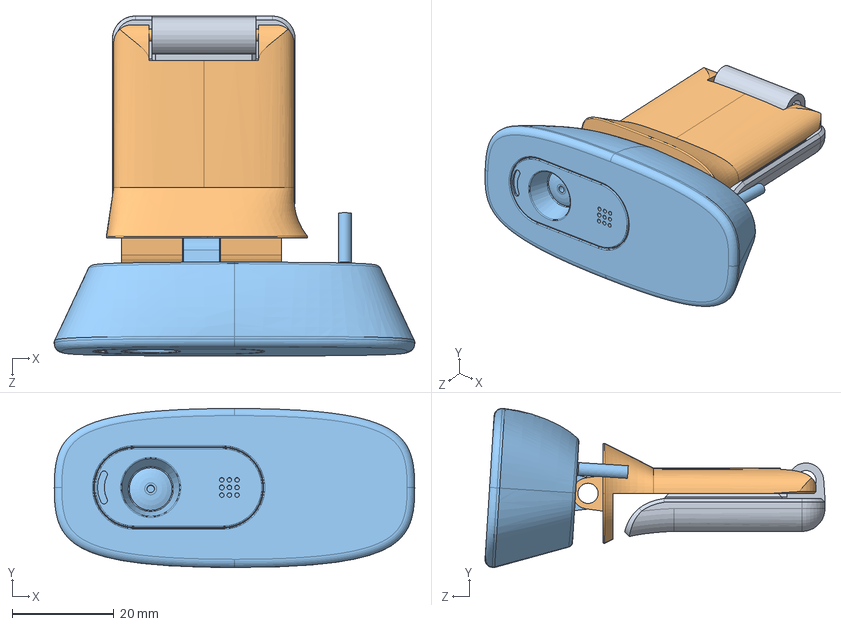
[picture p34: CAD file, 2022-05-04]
3d/c270/Logitech c270 Assembly.SLDASM
71.0 x 31.3 x 67.0 mm
Logitech c270c
Logitech c270b
Logitech c270

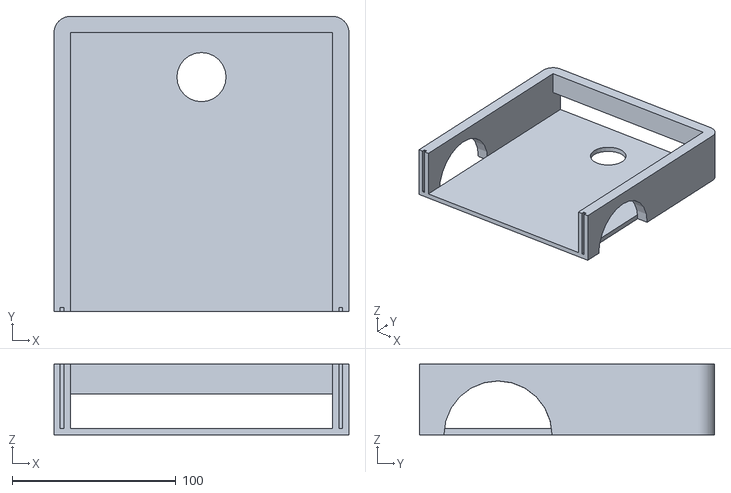
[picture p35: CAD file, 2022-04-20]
3d/stl/main_body.stl
180.0 x 180.2 x 43.3

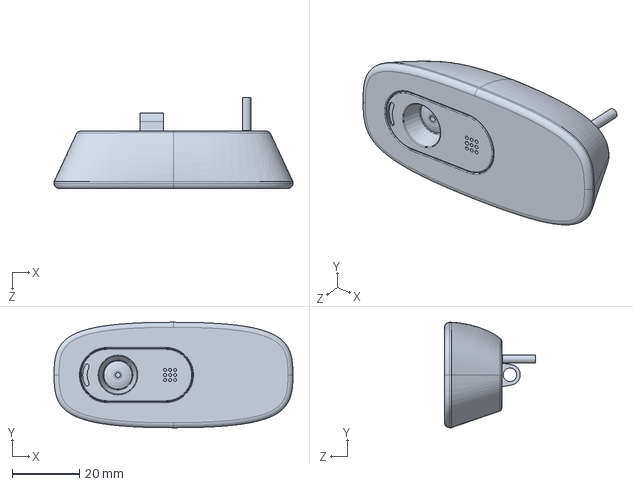
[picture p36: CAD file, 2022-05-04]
3d/c270/Logitech c270.SLDPRT
71.0 x 31.4 x 27.0 mm

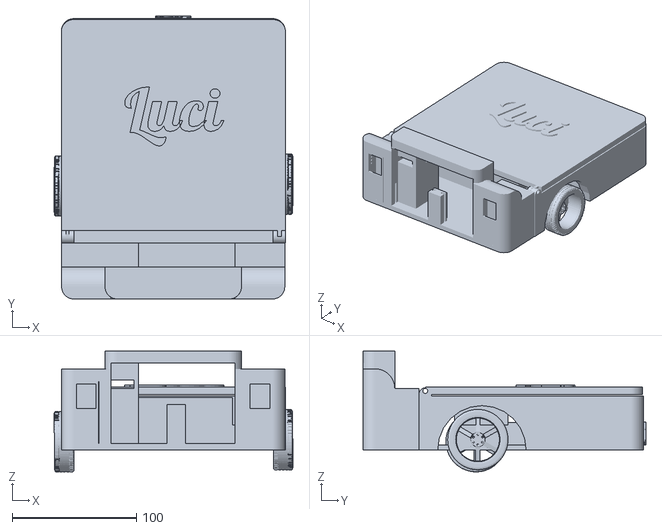
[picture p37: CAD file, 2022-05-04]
3d/stl/disenybasic.stl
191.9 x 227.4 x 97.1

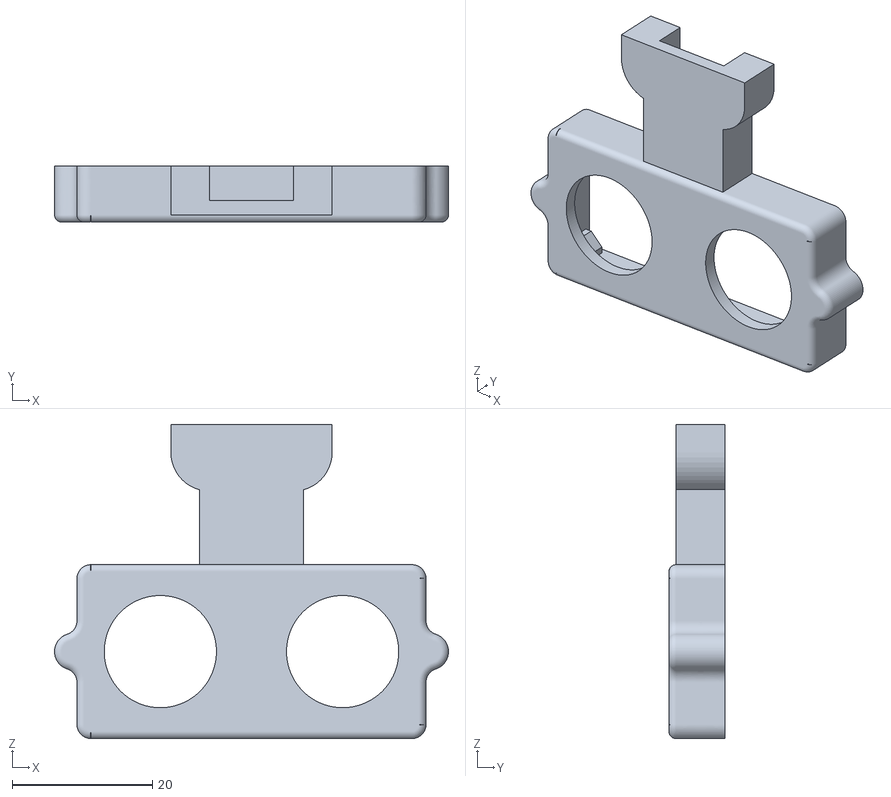
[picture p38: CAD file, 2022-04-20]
3d/stl/modul-ultrasound1-dht11/front.stl
56.2 x 8.00 x 44.8

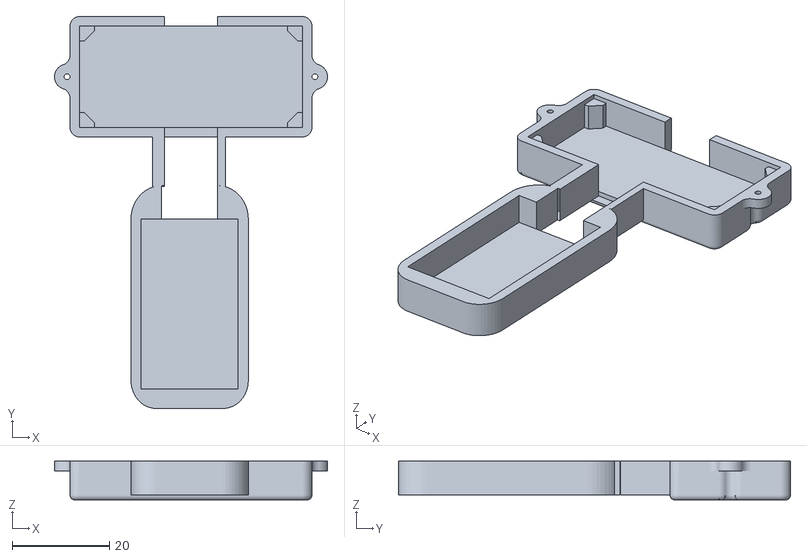
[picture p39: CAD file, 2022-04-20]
3d/stl/modul-ultrasound2-gas-sensor/back.stl
56.2 x 80.7 x 8.00

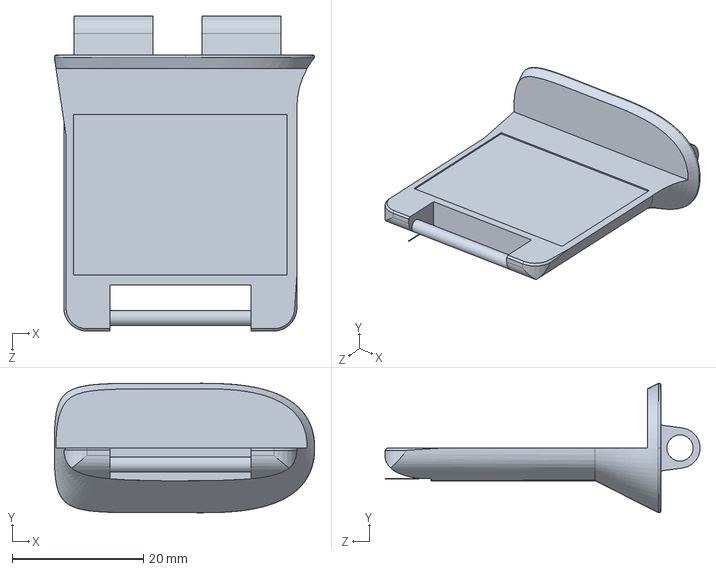
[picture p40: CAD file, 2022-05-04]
3d/c270/Logitech c270b.SLDPRT
39.7 x 19.7 x 48.0 mm

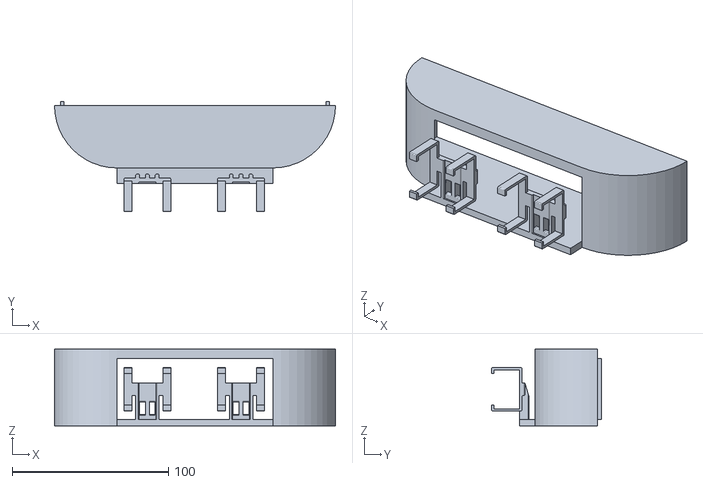
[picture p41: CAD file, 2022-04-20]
3d/stl/front_sensor_part.stl
180.0 x 70.4 x 49.3

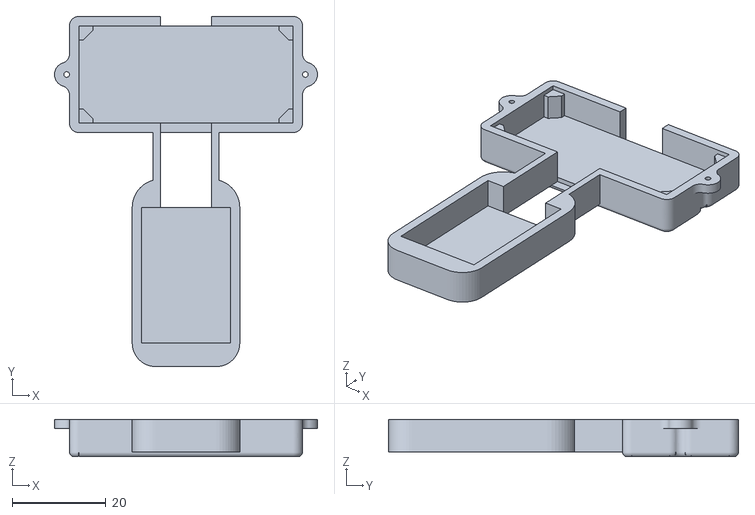
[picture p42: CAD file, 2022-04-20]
3d/stl/modul-ultrasound1-dht11/back.stl
56.2 x 74.8 x 8.00

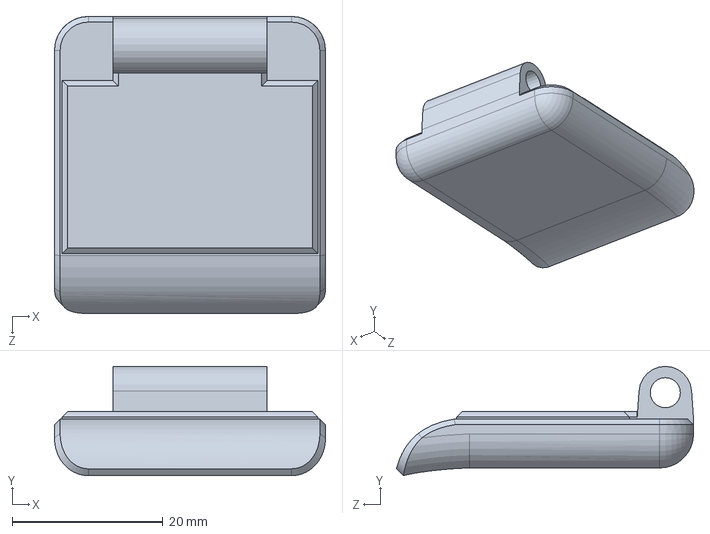
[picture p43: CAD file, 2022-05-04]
3d/c270/Logitech c270c.SLDPRT
36.0 x 14.5 x 39.5 mm

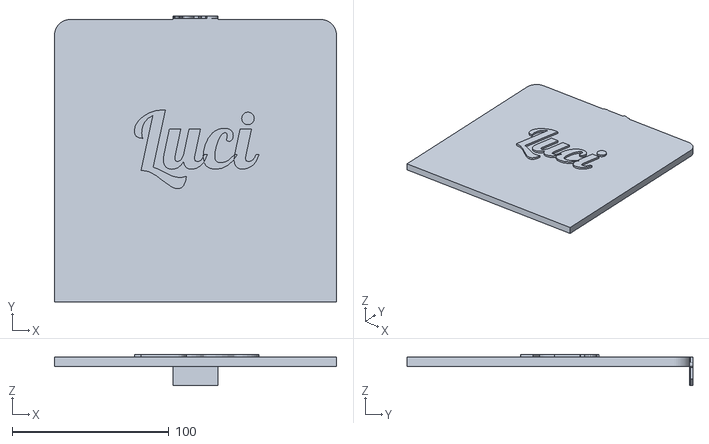
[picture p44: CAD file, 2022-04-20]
3d/stl/tapa.stl
180.0 x 182.3 x 20.0

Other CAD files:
3d/stl/modul-ultrasound2-gas-sensor/front.stl
3d/disenybasic.stl

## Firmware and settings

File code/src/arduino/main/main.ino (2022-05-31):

// DHT Temperature & Humidity Sensor
// Unified Sensor Library Example
// Written by Tony DiCola for Adafruit Industries
// Released under an MIT license.

// REQUIRES the following Arduino libraries:
// - DHT Sensor Library: https://github.com/adafruit/DHT-sensor-library
// - Adafruit Unified Sensor Lib: https://github.com/adafruit/Adafruit_Sensor

#include <Adafruit_Sensor.h>
#include <DHT.h>
#include <DHT_U.h>
#include "ArduinoJson.h"

// TODOS LOS PINS A DEFINIR

// MOTOR B
#define EnB 6
#define inB1 5
#define inB2 8

// MOTOR A
#define EnA 9
#define inA1 10
#define inA2 13

// MOTOR VARIABLES
String inString = "";    // concatenació de tota la instrucció
int inChar = 0;          // valor rebut actualment
int thruster_left;       // valor motor esquerra
int thruster_right;      // valor motor dret
int save_as_second = false; // flag per saber a quin motor guardar el valor

// ULTRASOUND SENSOR 1
#define UltraSoundTrigPin_1 7
#define UltraSoundEchoPin_1 3

// ULTRASOUND SENSOR 2
#define UltraSoundTrigPin_2 12
#define UltraSoundEchoPin_2 11

#define DHTPIN 2     // Digital pin connected to the DHT sensor 

const int MQ_PIN = A0;      // Pin del sensor


// DHT 1 SENSOR VARIABLES (TEMPERATURE & HUMIDITY)
#define DHTTYPE    DHT11     // Utilitzem el DHT 11
DHT_Unified dht(DHTPIN, DHTTYPE);

uint32_t delayMS;

// GAS SENSOR VARIABLES

const int RL_VALUE = 5;      // Resistencia RL del modulo en Kilo ohms
const int R0 = 10;          // Resistencia R0 del sensor en Kilo ohms
// Datos para lectura multiple
const int READ_SAMPLE_INTERVAL = 100;    // Tiempo entre muestras
const int READ_SAMPLE_TIMES = 5;       // Numero muestras
// Ajustar estos valores para vuestro sensor según el Datasheet
// (opcionalmente, según la calibración que hayáis realizado)
const float X0 = 200;
const float Y0 = 1.7;
const float X1 = 10000;
const float Y1 = 0.28;
// Puntos de la curva de concentración {X, Y}
const float punto0[] = { log10(X0), log10(Y0) };
const float punto1[] = { log10(X1), log10(Y1) };
// Calcular pendiente y coordenada abscisas
const float scope = (punto1[1] - punto0[1]) / (punto1[0] - punto0[0]);
const float coord = punto0[1] - punto0[0] * scope;


void initL298nPins(){
   pinMode (inA1, OUTPUT);
   pinMode (inA2, OUTPUT);
   pinMode (inB1, OUTPUT);
   pinMode (inB2, OUTPUT);
   pinMode (EnA, OUTPUT);
   pinMode (EnB, OUTPUT);
}

void initDHTSensor() {
  // Initialize device.
  dht.begin();
  // Print temperature sensor details.
  sensor_t sensor;
  dht.temperature().getSensor(&sensor);
  // Print humidity sensor details.
  dht.humidity().getSensor(&sensor);
  // Set delay between sensor readings based on sensor details.
  delayMS = sensor.min_delay / 1000;
  Serial.println(delayMS);

}

void setup() {
  Serial.begin(9600);
  initDHTSensor();
  initL298nPins();
}

float readDHTTemp() {
  // Get temperature event and print its value.
  sensors_event_t event;
  dht.temperature().getEvent(&event);
  if (isnan(event.temperature)) {
    Serial.println(F("Error reading temperature!"));

    return 0.0;
  }
  else {
    return event.temperature;
  }
}

float readDHTHumidity() {
  // Get humidity event and print its value.
  sensors_event_t event;
  dht.humidity().getEvent(&event);
  if (isnan(event.relative_humidity)) {
    Serial.println(F("Error reading humidity!"));

    return 0.0;
  }
  else {
    return event.relative_humidity;
  }
}

// Obtener la resistencia promedio en N muestras
float readMQ(int mq_pin)
{
  float rs = 0;
  for (int i = 0; i < READ_SAMPLE_TIMES; i++) {
    rs += getMQResistance(analogRead(mq_pin));
    delay(READ_SAMPLE_INTERVAL);
  }
  return rs / READ_SAMPLE_TIMES;
}
// Obtener resistencia a partir de la lectura analogica
float getMQResistance(int raw_adc)
{
  return (((float)RL_VALUE / 1000.0 * (1023 - raw_adc) / raw_adc));
}
// Obtener concentracion 10^(coord + scope * log (rs/r0)
float getConcentration(float rs_ro_ratio)
{
  return pow(10, coord + scope * log(rs_ro_ratio));
}




long readUltrasonicDistance (int triggerPin, int echoPin)
{
  pinMode (triggerPin, OUTPUT); // Clear the trigger
  digitalWrite (triggerPin, LOW) ;
  delayMicroseconds (2);
  // Sets the trigger pin to HIGH state for 10 microseconda
  digitalWrite (triggerPin, HIGH);
  delayMicroseconds (10);
  digitalWrite (triggerPin, LOW) ;
  pinMode (echoPin, INPUT);
  // Reads the echo pin, and returns the sound wave travel time
  return pulseIn (echoPin, HIGH);
}

// Funcions pels motors
void motors_forward( int speed)
{
  if (speed < 0) speed =0;
  if (speed > 255) speed = 255;
  
 //dirreccio motor A
 digitalWrite (inA1, HIGH);
 digitalWrite (inA2, LOW);
 analogWrite (EnA, speed); 
 //direccio motor B
 digitalWrite (inB1, HIGH);
 digitalWrite (inB2, LOW);
 analogWrite (EnB, speed); 
}

void motors_backward ( int speed)
{
  if (speed < 0) speed =0;
  if (speed > 255) speed = 255;
  
 //dirreccio motor A
 digitalWrite (inA1, LOW);
 digitalWrite (inA2, HIGH);
 analogWrite (EnA, speed); 
 //direccio motor B
 digitalWrite (inB1, LOW);
 digitalWrite (inB2, HIGH);
 analogWrite (EnB, speed);
}

void motors_turn_forward( int speed_left, int speed_right)
{
  if (speed_left < 0) speed_left =0;
  if (speed_left > 255) speed_left = 255;
  if (speed_right < 0) speed_right =0;
  if (speed_right > 255) speed_right = 255;
    
 digitalWrite (inA1, HIGH);
 digitalWrite (inA2, LOW);
 analogWrite (EnA, speed_left); 

 digitalWrite (inB1, HIGH);
 digitalWrite (inB2, LOW);
 analogWrite (EnB, speed_right);
}

void motors_turn_backward( int speed_left, int speed_right)
{
  if (speed_left < 0) speed_left =0;
  if (speed_left > 255) speed_left = 255;
  if (speed_right < 0) speed_right =0;
  if (speed_right > 255) speed_right = 255;
    
 digitalWrite (inA1, LOW);
 digitalWrite (inA2, HIGH);
 analogWrite (EnA, speed_left); 

 digitalWrite (inB1, LOW);
 digitalWrite (inB2, HIGH);
 analogWrite (EnB, speed_right);
}

void motors_turn_leftforward_rightbackward( int speed_left, int speed_right)
{
  if (speed_left < 0) speed_left =0;
  if (speed_left > 255) speed_left = 255;
  if (speed_right < 0) speed_right =0;
  if (speed_right > 255) speed_right = 255;
    
 digitalWrite (inA1, HIGH);
 digitalWrite (inA2, LOW);
 analogWrite (EnA, speed_left); 

 digitalWrite (inB1, LOW);
 digitalWrite (inB2, HIGH);
 analogWrite (EnB, speed_right);
}

void motors_turn_rightforward_leftbackward( int speed_left, int speed_right)
{
  if (speed_left < 0) speed_left =0;
  if (speed_left > 255) speed_left = 255;
  if (speed_right < 0) speed_right =0;
  if (speed_right > 255) speed_right = 255;
    
 digitalWrite (inA1, LOW);
 digitalWrite (inA2, HIGH);
 analogWrite (EnA, speed_left); 

 digitalWrite (inB1, HIGH);
 digitalWrite (inB2, LOW);
 analogWrite (EnB, speed_right);
}

void motors_turn_left_still( int speed)
{
  if (speed < 0) speed =0;
  if (speed > 255) speed = 255;
  
 digitalWrite (inA1, LOW);
 digitalWrite (inA2, HIGH);
 analogWrite (EnA, speed); 
 
 digitalWrite (inB1, HIGH);
 digitalWrite (inB2, LOW);
 analogWrite (EnB, speed); 
}

void motors_turn_right_still( int speed)
{
  if (speed < 0) speed =0;
  if (speed > 255) speed = 255;
  
 digitalWrite (inA1, HIGH);
 digitalWrite (inA2, LOW);
 analogWrite (EnA, speed); 
 digitalWrite (inB1, LOW);
 digitalWrite (inB2, HIGH);
 analogWrite (EnB, speed); 
}

void motors_stop()
{
 digitalWrite (inA1, LOW);
 digitalWrite (inA2, LOW);
 analogWrite (EnA, 0); 
 digitalWrite (inB1, LOW);
 digitalWrite (inB2, LOW);
 analogWrite (EnB, 0);
}

void motors_read_serial() {
  // El serial read funciona amb el format "10,0;" (sense les cometes).
  // L'exemple significa que el motor esquerra va a velocitat 10 i el dret a velocitat 0.
  
  /// Read serial data
  if (Serial.available()) {  // si serial data està disponible
    inChar = Serial.read();  // guardem l'últim byte
    inString += char(inChar);// concatenem
        
    /// quan detectem una coma, guardem el valor i l'assignem a left
    if (inChar == ',') {
      if (save_as_second == false) { 
        thruster_left = inString.toInt(); 
        inString = "";               
        save_as_second == true;      
      }
    }
    /// al detectar una semicolon, guardem l'últim valor a Right
    if (inChar == ';') {     
      thruster_right = inString.toInt();
      inString = "";        
      save_as_second = false;

      /// Ja tenim tots els valors necessaris, movem el motor
      Serial.print("Left Thruster:"); 
      Serial.println(thruster_left);
      Serial.print("Right string: ");
      Serial.println(thruster_right);

      
      // Mirem si es vol moure endavant o endarrere i cridem a la funció corresponent
      if (thruster_left >= 0 && thruster_right >=0){
       return motors_turn_forward(thruster_left, thruster_right);
      }

      return motors_turn_backward(-1*thruster_left, -1*thruster_right);


      
      
      
    }
  }
}

DynamicJsonDocument doc(1024);

void emit_serial() {
  delay(delayMS);
  motors_turn_forward(150,150);
  float dht11_temp = readDHTTemp();
  float dht11_humidity = readDHTHumidity();

  int ultrasound_sensor_1_distance = 0.01723 * readUltrasonicDistance (UltraSoundTrigPin_1, UltraSoundEchoPin_1);
  int ultrasound_sensor_2_distance = 0.01723 * readUltrasonicDistance (UltraSoundTrigPin_2, UltraSoundEchoPin_2);

  float rs_med = readMQ(MQ_PIN);      // Obtener la Rs promedio
  float gas_concentration = getConcentration(rs_med / R0); // Obtener la concentración

  doc["gas_concentration"] = gas_concentration;
  doc["ultrasound_sensor_1_distance"]   = ultrasound_sensor_1_distance;
  doc["ultrasound_sensor_2_distance"]   = ultrasound_sensor_2_distance;
  doc["dht11_humidity"] = dht11_humidity;
  doc["dht11_temp"] = dht11_temp;

  serializeJson(doc, Serial);
  Serial.println("");
}

void loop() {
  motors_read_serial();
  emit_serial();
}

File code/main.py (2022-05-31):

#!/usr/bin/env python

#from src.computer_vision.video_stabilization.video_stabilization import video
from src.deploy.server.server import *
from src.deploy.sensors.sensors  import Sensors


from src.deploy.video.video_input import *
from src.deploy.video.video_output import *
from src.deploy.video.termal_camera_input import *
import os

from src.voice.voice import *

def on_start():
    print("[INFO] on_start video capture")

    return

def on_finish():
    print("[INFO] on_finish video capture")
    # Release the video capture object
    video_capture.stop()
    cv2.destroyAllWindows()

    return

# Tenim 3 threads
# - Un per captura de video de webcam
# - Un per captura de video de termica
# - Un per mostrar el video de la webcam

width = 640
height = 480

video_capture =  VideoInput(0,  width=width, height=height) # Inicialitza el video input
video_capture.on_start = on_start # Assigna la funcio on_start al event on_start
video_capture.on_finish = on_finish # Assigna la funcio on_finish al event on_finish

termal_video_input =  TermalCameraInput(width=width, height=height) 

video_output = VideoOutput(video_capture.frame,  name = 'Hyper rapido', type_detector="SSD") # inicialitzem la sortida de video
video_output.on_start = None # assignem el metode on_start que es cridara al iniciar la sortida de video
video_output.on_finish = on_finish # assignem el metode on_finish a la classe VideoOutput per a que es cridi quan acabi el video o cliquem la lletra q


sensors = Sensors(use_serial=True, port='/dev/ttyACM0') # inicialitzem els sensors
server = Server(sensors, video_capture,  video_output, termal_video_input=termal_video_input) # inicialitzem el servidor

# save_location = os.path.join(server.root_path, "/static/", "voice_response.json")
save_location = server.root_path + '/static/voice_response.json'
# print(server.root_path)
print(save_location)

# '/home/pi/RLP-PLAB/code/src/deploy/server'

voice_input = VoiceInput(lang_code="es-ES", save_location = save_location)


video_capture.start() # inicialitzem la captura de video de la camera
termal_video_input.start()
video_output.start() # inicialitzem la sortida de video

voice_input.start()
sensors.start_reading()
server.start()

termal_video_input.join()
video_capture.join() # espera que acabi la captura de video de la camera 

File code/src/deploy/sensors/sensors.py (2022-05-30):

import serial
import json 

class Sensors:
    def __init__(self, port='/dev/ttyACM0', baudrate=9600, use_serial = False):
        if use_serial:
            self.ser = serial.Serial(port, baudrate, timeout=0)

        # ho tenim com objecte per si volem accedir desde python pero per el websocket enviare el json
        self.gas_concentration = 0.0
        self.ultrasound_sensor_1_distance = 0.0
        self.ultrasound_sensor_2_distance = 0.0
        self.dht11_humidity = 0.0
        self.dht11_temp = 0.0
        self.json_value = ""
        # self.ser.reset_input_buffer()
    
    def parse_sensors(self, json_text):
        print("Parsing: " + str(json_text))        
        print(len(json_text))

        if 'gas_concentration' in json_text:
            json_dict = json.loads(json_text)


            self.gas_concentration = json_dict['gas_concentration']
            self.ultrasound_sensor_1_distance = json_dict['ultrasound_sensor_1_distance']
            self.ultrasound_sensor_2_distance = json_dict['ultrasound_sensor_2_distance']
            self.dht11_humidity = json_dict['dht11_humidity']
            self.dht11_temp = json_dict['dht11_temp']
            self.json_value = json_dict
        else:
            print("Error parsing json")
            self.json_value = self.error_data()
            return self.json_value

        return json_text

    def error_data(self):
        json_text = {}
        json_text["gas_concentration"] = self.gas_concentration
        json_text["ultrasound_sensor_1_distance"] =  self.ultrasound_sensor_1_distance
        json_text["ultrasound_sensor_2_distance"] = self.ultrasound_sensor_2_distance
        json_text["dht11_humidity"] = self.dht11_humidity
        json_text["dht11_temp"] = self.dht11_temp
        
        app_json = json.dumps(json_text)

        self.json_value = app_json

        return str(app_json)

    def start_reading(self):
        # while True:
        #     self.read_sensors()
        print("gello")

    def read_sensors(self):
        #if self.ser.in_waiting > 0:
        json_text = self.ser.readline().decode('utf-8')
        print(json_text)
        # if json_text is None or len(json_text) < 1:
        #     return self.parse_sensors(self.error_data())
            
        return self.parse_sensors(json_text)
        #else:
        #    print("No data available from arduino yet.")
        #     return self.parse_sensors(self.error_data())
    
    def get_sensor_values(self):
        return self.json_value
    
    def close(self):
        self.ser.close()
    

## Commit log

2022-04-05 feat: initial commit of 3d design
    [disenybasic.stl]
2022-04-05 feat: enganxe pel modul de davant
2022-04-11 feat: arduino code inital commit, need to test now
2022-04-11 fix: some bugs with websickets
    [sensors.py, server.py]
2022-04-12 feat: added second ultrasound sensor
2022-04-20 feat: sprint 1, stl v1.0
    [back.stl, front.stl, front_sensor_part.stl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]
2022-04-24 fixing enA and enB not connected to a PWM pin
    [hardware.fzz]
2022-04-24 feat: arduino motors and controller
2022-04-24 fix: invalid funcition name
    [main.ino]
2022-05-04 feaT: try using threads
2022-05-04 feat: threads and live streaming working
    [Logitech c270 Assembly.SLDASM, Logitech c270.SLDPRT, Logitech c270b.SLDPRT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]
2022-05-06 camera_test + camara (output)
    creacio de l'script per a realitzar una imatge desde python amb la pi noir
2022-05-10 feat: pi noir camera working with webcam stream at the same time on rp4
2022-05-11 documenataci de connectar el comandament
2022-05-11 read serial from Arduino so motors move
2022-05-16 termical camera
2022-05-17 new key binding and controls so it's more intuitive
    [controller-reader.py]
2022-05-30 move and delete documents termical camera
2022-05-30 feat: termal camera input with merge function by @ricardlol
2022-05-30 fix: termal camera working, speech to text refactoring
    [controller-reader.py, main.py, merge_image.py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]
2022-05-30 fixing read frequency and optimizing arduino code for motors
    [controller-reader.py, main.ino]
2022-05-31 Forma de creació de las Arrays
